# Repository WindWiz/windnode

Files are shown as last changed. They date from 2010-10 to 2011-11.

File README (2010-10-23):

WindWiz
=====================
WindWiz is an open-source weatherstation project. Its primary purpose is to act
as a wind sensor node along the coasts of southern Sweden. The measurements are 
sent back using IP over the cellular network (GPRS).

Features:
---------
* Measurements of wind speed and direction.
* Measurements of air temperature.
* Remote control/configuration via SMS.
* Periodical transmission of current wind conditions over GPRS to a 
configurable IP.
* Rugged design, must withstand rain, snow, temperatures from -20C to +40C.
* Solar powered, with battery backup.
* Reliable, 24/7 operation.
* Total buildcost, ~6000 SEK (swedish currency)

The primary focus of this project is the construction of the actual sensor node
hardware. It includes schematics of the electronics, software (with sourcecode)
running inside the embedded microcontroller, and mechanical details on the 
rugged casing. 

The data samples are transmitted over IP to another system responsible for data
collection and visualization. This is outside the scope of this project.

More information is available at the project homepage:

  http://vind.minimum.se/ (swedish only)

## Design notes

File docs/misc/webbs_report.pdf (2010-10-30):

# WeBBS

# The Weather Bulletin Board System

# Technical Manual

Fahid Jahrami, Arian Lalezari, Justin Lasiewicz,

# Joshua Miers, Nathan Seidle

# Revision: 27 April 2004

# Table of Contents

# H.3 Firstrun.exe | 95 H.4 Secondrun.exe | 96

# Table of Figures

# Table of Equations

# Table of Tables

# 1 Overview

# 1.1 Abstract

# The WeBBS team at the University of Colorado at Boulder designed the Weather Bulletin Board System for autonomous remote weather sensing. The

WeBBS weather station is completely powered by a solar cell charging circuit,

# and communicates wirelessly using cellular telephone technology. The station is programmed to periodically record and store weather conditions from four external sensors: a temperature, pressure, and humidity sensor, as well as an ultrasonic anemometer designed by the WeBBS team to record wind speed

and direction.

The weather conditions can be retrieved in three different ways. Users who are on‐site may use the on‐board LCD display, while off‐site users will have two methods to retrieve data. Users with cellular telephones with SMS service will able to send an SMS text message or a voice call to the station, which will record their telephone number and return an SMS message with weather conditions. Users who cannot access an SMS service will be able to browse weather conditions on a website that will be regularly updated by the weather

station.

# 1.2 Motivation

# While still a young program at only twelve years old, Colorado Crew has quickly grown from one of the most “underprivileged” rowing programs in the nation to one that regularly challenges established varsity teams in

national regattas.

Other than the financial and physical challenges shared by all crew team, the Colorado programs faces an obstacle not common to most established teams: the unpredictable and volatile weather conditions in Boulder. With early morning practices, there is often no way to judge the weather conditions at the Boulder Reservoir without requiring the entire team to arrive at the regular practice time. If practice is cancelled, the entire team is inconvenienced by

having had come to the Reservoir, only to return home.

# With this in mind, it has become the goal of the WeBBS team to provide an

autonomous and financially practical solution for the Colorado Crew team.

# However, we feel that the applications of our product extend well beyond the scope of the Colorado Crew team. For example, ski resorts in Colorado and

elsewhere share the same need for favorable weather to ensure good skiing conditions to their customers. With a weather station at each ski lift, a major resort would easily be able to monitor the conditions throughout their terrain at any time. The same goes for other large‐scale outdoor facilities such as

airports, amusement parks, golf courses, etc.

# 1.3 Block Diagram

# 1.3.1 Power Platform

# 1.3.2 Main Board

# Communications

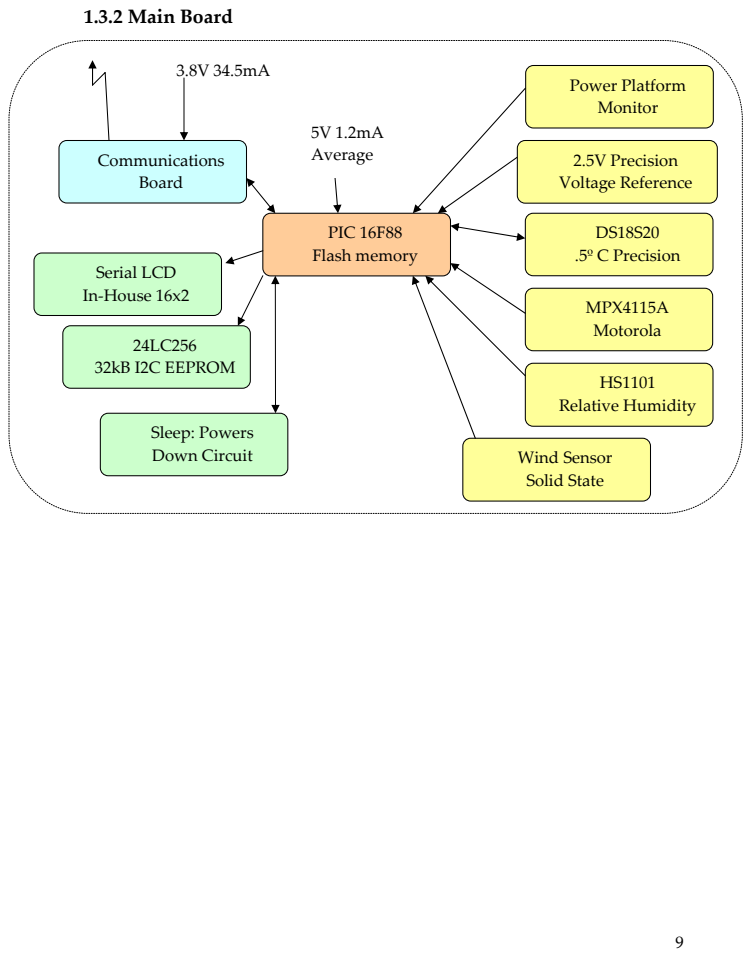
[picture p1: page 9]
DS18S20 .5º C Precision; PIC 16F88 Flash memory; MPX4115A Motorola; HS1101 Relative Humidity; 24LC256 32kB I2C EEPROM; Board; Serial LCD In‐House 16x2; 2.5V Precision Voltage Reference; Wind Sensor Solid State; Power Platform Monitor; Sleep: Powers Down Circuit; 5V 1.2mA Average

# 2 Enclosure

The enclosure of the WeBBS weather station consists of two main components,

# the main enclosure containing the primary electrical systems and the

anemometer enclosure, containing the wind sensor.

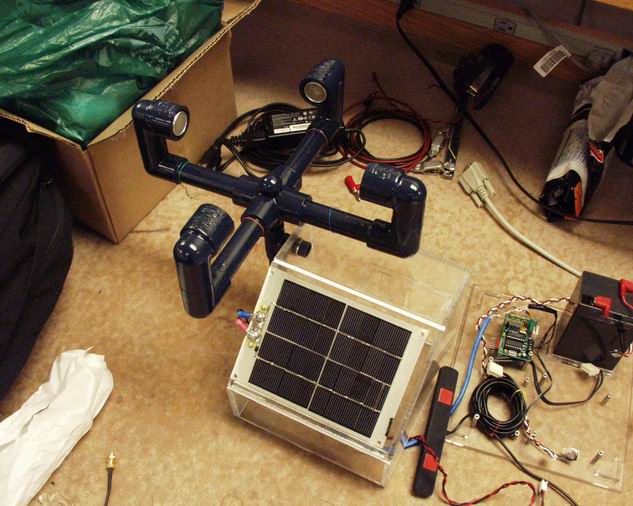
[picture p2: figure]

# Figure 1: Main Housing

# 2.1 Main Enclosure

# 2.1.1 Design Requirement

# The primary design goals of the main enclosure are:

# 1. To minimize the size of the enclosure without compromising the

accessibility of individual internal components.

# 2. To minimize the vulnerability of the internal components to the potentially

harmful external weather conditions.

# 2.1.1.1 Size

# The three components presenting the primary restrictions on the size and shape of the main enclosure are the ultrasonic anemometer, the battery, and the solar panel. Because of its location on the side of the main enclosure, the

ultrasonic anemometer posed a potential threat of toppling the main enclosure.

Furthermore, to adequately fasten the anemometer, we provided that the two fastening locations be at least 3.5 inches apart to maintain stability. For further support, we positioned the battery on the opposite side of the enclosure as a counter‐balance. The battery posed similar height requirements for the enclosure to those of the anemometer. The slanted face of the weather station is designed to provide maximal exposure to the sun for the solar panel. Since

Boulder is at 40° north latitude, the slanted face is elevated by 40°.

# Furthermore, the width of the enclosure is determined by the longest edge of the solar panel. Again, the width requirements posed by the inclusion of the printed circuit boards inside the enclosure were similar to those of the solar

panel.

# 2.1.1.2 Weatherproofing

The two components presenting the primary restrictions on the weatherproofing of the main enclosure are the ultrasonic anemometer and the solar panel. To affix the anemometer to the main enclosure, our design requires two holes in one side of the enclosure. Because holes present a weatherproofing challenge, the lower hole is used doubly to affix the anemometer and provide a snorkel to ventilate the interior of the enclosure

and provide access to external weather conditions for the temperature,

pressure, and humidity sensors. The solar panel presents two challenges to weatherproofing. First, like the anemometer, the leads of the solar panel must be connected to the internal electrical components of the weather station. In order to avoid compromising the structural integrity of the anemometer enclosure, we opt to provide a small hole uniquely for the purpose of the

connectivity of the solar panel. Second, because the solar panel must be tilted, we must weatherproof two non‐perpendicular seams.

# 2.1.2 Materials

The main enclosure is constructed entirely from 0.25‐inch thick clear Plexiglas.

# The perpendicular planes of the enclosure are fastened and weatherproofed with Plastruct plastic solvent cement. The holes and non‐perpendicular solar

panel plane are weatherproofed with weather‐resistant caulk.

# 2.1.3 Construction and Weatherproofing

# All planes of the main enclosure were cut using the Radius laser cutter in the Integrated Teaching and Learning Laboratory (ITLL) machine shop at the

University of Colorado at Boulder.

# All planes were fastened and weatherproofed with Plastruct solvent cement

and caulk.

# 2.1.4 Testing

# The main enclosure was tested under extreme high and low temperature and humidity conditions as well as direct sunlight exposure to ensure the

sustainability of its resistance to weather and internal moisture.

# The enclosure was also tested against stress by applying controlled forces to

each of its exposed surfaces.

# 2.1.5 Drawings

# 2.1.5.1 Conceptual Drawing

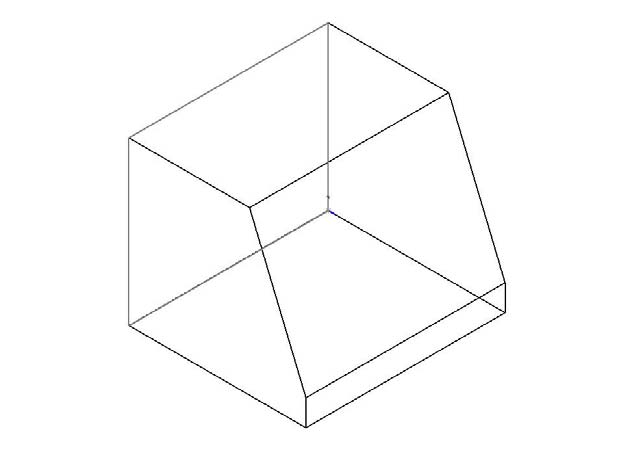
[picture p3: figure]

# Figure 2: 3‐D Conceptual Drawing

# 2.1.5.2 Parts Drawings

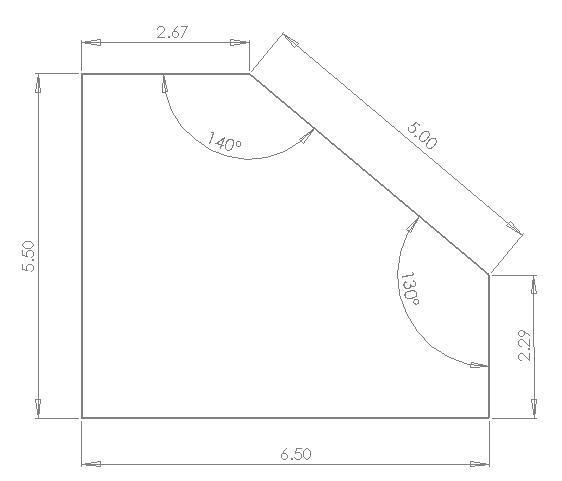
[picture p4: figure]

# Figure 3: Main Enclosure (Left)

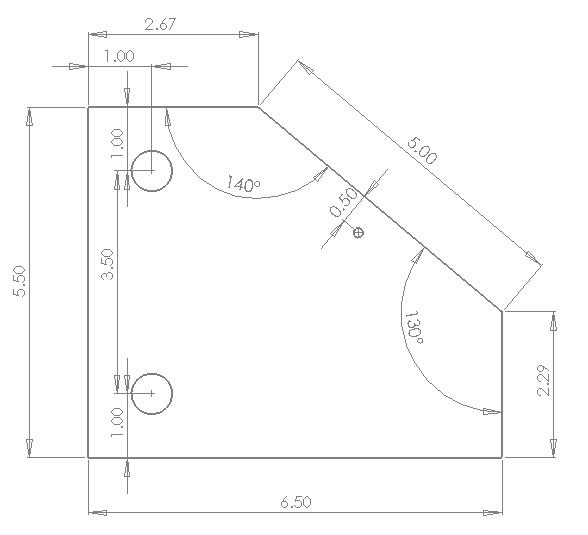
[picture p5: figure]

# Figure 4: Main Enclosure (Right)

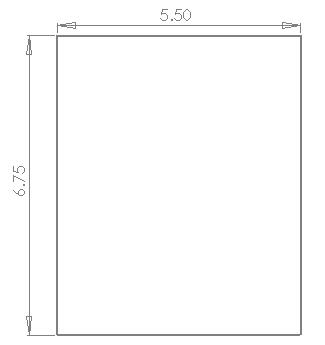
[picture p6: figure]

# Figure 5: Main Enclosure (Back)

# Figure 6: Main Enclosure (Top)

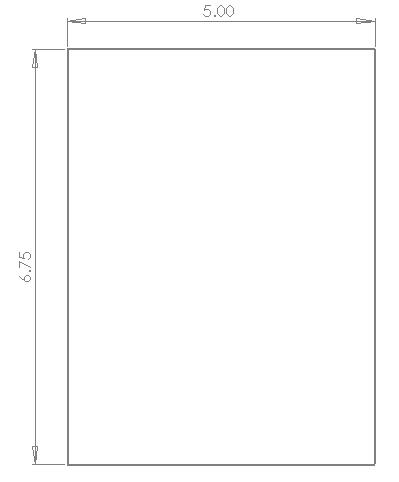
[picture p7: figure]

# Figure 7: Main Enclosure (Solar)

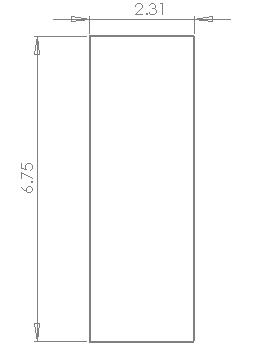
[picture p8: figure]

# Figure 8: Main Enclosure (Front)

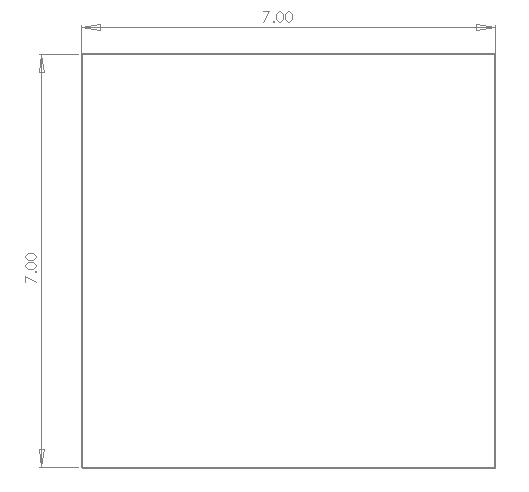
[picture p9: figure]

# Figure 9: Main Enclosure (Base)

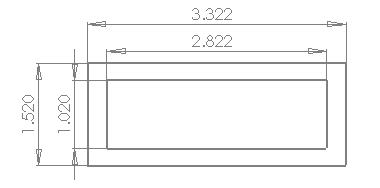
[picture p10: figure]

# Figure 10: Main Enclosure (LCD Frame)

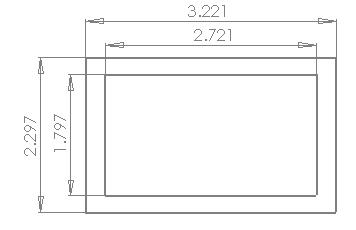
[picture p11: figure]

# Figure 11: Main Enclosure Battery Frame

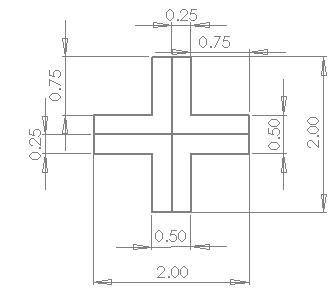
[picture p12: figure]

# Figure 12: Main Enclosure Braces

# 2.2 Anemometer Enclosure

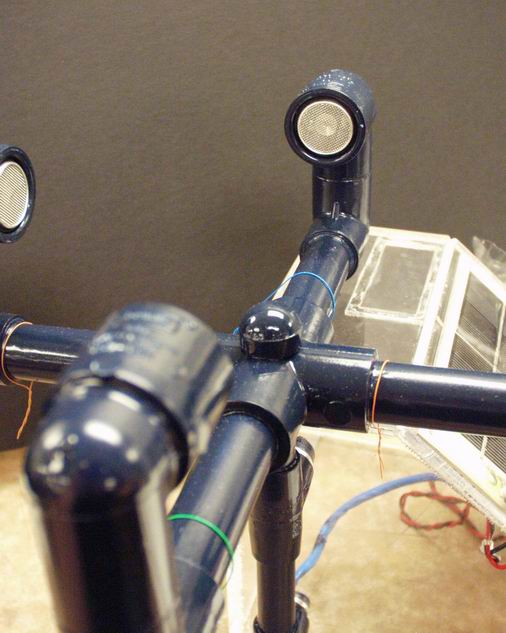
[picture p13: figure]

# Figure 13: Anemometer Enclosure

# 2.2.1 Design Requirements

# The primary design goals of the anemometer enclosure are: 1. To provide stability for the anemometer assembly and align the pairs of

ultrasonic sensors.
2. To weatherproof the critical components of the anemometer.

# 2.2.1.1 Stability

Because of the required size of the anemometer, it is critical that it remains stable and that the ultrasonic sensors remain aligned. For stability, we provide two locations to anchor the anemometer enclosure to the side of the main enclosure. To maintain alignment, we provide that the wind sensor remains smaller than 12 inches in any horizontal direction, and that all connections are

permanently fastened with PVC glue.

# 2.2.1.2 Weatherproofing

The primary concern for weatherproofing the anemometer enclosure is the protection of the internal wires tying the anemometer to the internal components of the weather station. To do this, all connections are sealed and weatherproofed with standard PVC glue. The ultrasonic sensors are weather resistant and are sealed with two o‐rings to protect the inner wires of the

enclosure.

# 2.2.2 Materials

The top assembly of the enclosure requires the use of 0.75‐inch PVC pipe, in order to house the ultrasonic sensors. The vertical assembly of the enclosure is constructed with 0.5‐inch PVC pipe to facilitate the connections to the main enclosure and the top assembly. The ultrasonic sensors are fastened with o‐

rings and all seams are sealed with standard PVC glue.

Each transducer is secured at a distance of 7.3” from its pair.

# 2.2.3 Testing

The enclosure was tested for weather resistance.

# 3 Electrical Systems

There are six main electrical systems in the WeBBS weather station: the main system containing the main microcontroller and several peripheral sensors, the cell module system containing the communications platform, the wind module system containing the microcontroller for the anemometer, the LCD system providing easy‐to‐read on‐site data, the power platform consisting of the solar

panel, battery, and several voltage regulators, and the website receiver station, which logs recorded weather data to a Internet‐available text file.

# 3.1 Main Board

# The main board is responsible for the central processing and monitoring of the weather station. In addition to the primary controller and memory device, the

main board contains three of the four weather sensors.

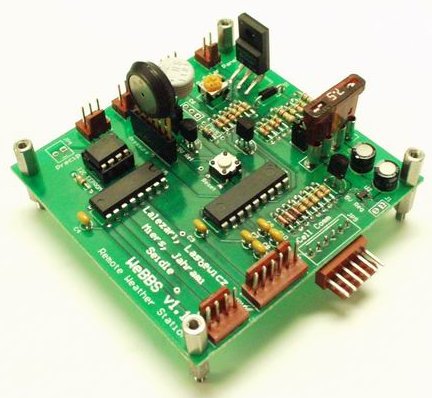
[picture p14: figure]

# Figure 14: Main Board

# 3.1.1 Microcontroller

All electrical systems are coordinated by a Microchip 16F88 microcontroller.

# The 16F88 features the ability to switch clock speeds in real time. To conserve power, the processor is kept at 31.25kHz except while in data recording or communications mode. In order to quicken data processing and

communication, the microcontroller switches to high‐speed mode at 8MHz.

# The 16F88 has 4kb of on‐board Flash program memory. This simplifies the system architecture by minimizing the number of external components

required.

# The 16F88 features the ability to interface to analog devices via seven software‐

configurable analog‐to‐digital channels.

# Because the 16F88 has the ability to change its program memory space on the fly, a proprietary boot loader was developed prior to the project to aide in

programming and debugging.

# All communication protocols (I²C, Dallas 1‐Wire, TTL Serial, RS232) are mimicked with software routines. For debugging purposes, the onboard

UART was utilized.

See Appendix A for microcontroller code.

See Data Sheet Packet for extra information on the boot loader and 16F88.

# 3.1.2 Memory

# The main memory device on the board is the Microchip 24LC256. The primary

use of the EEPROM is to log recorded weather conditions.

# The 24LC256 has 256kb of available flash memory, which gives us enough memory space to record up to 2,000 complete weather station status arrays – or

almost one week of weather conditions at 8 bytes per recording.

The 24LC256 interfaces on the I²C bus protocol.

See Data Sheet Packet for extra information on the 24LC256.

# 3.1.3 Temperature Sensor

The temperature sensor is an off‐the‐shelf sensor from Dallas Semiconductor.

# The DS18S20 measures temperatures from –55°C to +125°C (about ‐67°F to +257°F) with ±0.5°C accuracy. For our purposes, we have limited the

sensitivity of the device to ±1°C (about ±2°F).

The DS18S20 interfaces on the Dallas 1‐Wire protocol.

See Data Sheet Packet for extra information on the DS18S20.

# 3.1.4 Pressure Sensor

# The barometric pressure sensor is an off‐the‐shelf sensor from Motorola. The MPX4115A measures pressure with ±1.5% accuracy between 0°C and 85°C (about 32°F to 185°F). For our purposes, to include a broader range of

temperatures, we have limited the sensitivity of the device to ±5%.

# The MPX4115A interfaces through the TI 4051 8‐channel analog multiplexer to

the on‐board analog‐to‐digital converter of the 16F88.

See Data Sheet Packet for extra information on the MPX4115A.

# 3.1.5 Humidity Sensor

# The relative humidity sensor is an off‐the‐shelf sensor from Humirel. The HS1101 measures relative humidity with ±2% accuracy between –40°C and100°C (about –40°F to 212°F). For our purposes, we have limited the

sensitivity of the device to ±5%.

# The Humidity is determined through observation of the discharge RC time constant of a variable capacitor conjoined with a 983kΩ resistor. The capacitor

# is connected to the microcontroller on a pin that can be changed on the fly

between being an input and output pin. When the pin is set as an output pin,

the capacitor is charged to 5V. It is then discharged through the resistor, after the pin is changed to an input pin. The input pin is a transistor‐to‐transistor‐ logic level input. The TTL threshold for the 16F88 is 2V. Therefore, we can determine the internal capacitance of the sensor by using the equation:

# Equation 1: Humidity Variable Capacitance

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
# From the measured capacitance, we can determine the relative humidity using

a look‐up table derived from the HS1101 data sheet.

See Data Sheet Packet for extra information on the HS1101.

# 3.1.6 Power Requirements

# To conserve power, the main board will actively control the power to each device. Unless the weather station is in recording or communicating mode, all devices will remain powered down, and the microcontroller itself will be in low‐frequency sleep mode. Weather will be recorded and logged every five

minutes, and communications will occur every 15 minutes.

# With only peripheral sensors active, the main board requires 14.3mA to operate. When the microcontroller is set in low‐frequency sleep mode, the current consumption of the main board falls to 12.1mA with peripheral sensors active, and only 960µA with all peripheral sensors powered down. Because

# the main board will only take one five‐second reading every five minutes, we

will draw an average of 1.2mA of current from the main board.

# In order to monitor the current consumption of the board, a pair of leads is available to connect an Ammeter in series with the main power supply of the

board. For field operation, this pair of leads will be connected with a jumper.

# 3.1.7 Schematics

See Appendix B for schematics and PCB layout for the main board.

# 3.2 Communications Board

# The communications board is responsible for operating the wireless relay

between the weather station and a remote user.

# The communications board houses the Telit GM862‐PCS cellular telephone

module, powered by the Analog Devices LT1528 voltage regulator.

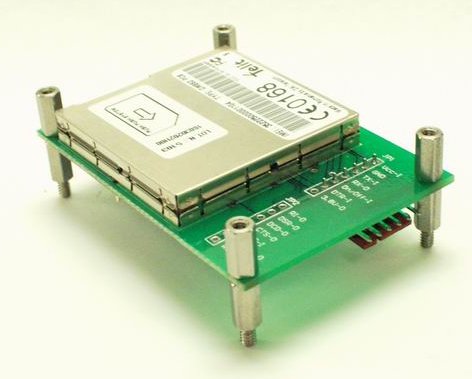
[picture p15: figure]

# Figure 15: Communications Board

# 3.2.1 GSM module

# The GM862‐PCS module has the full suite GPRS abilities: Short Messaging Service (SMS), HyperText Markup Language (HTML), Electronic Mail (E‐

Mail), as well as standard modem and voice capabilities.

# Users must provide a Subscriber Information Module (SIM) card that is

activated under a standard GSM cellular telephone account.

# Support for the GM862‐PCS module can be found by creating an account at the

support forum at http://www.modem‐gsm.de/forum.

See Data Sheet Packet for extra information on the GM862‐PCS.

# 3.2.2 Tri Band Antenna

# The North American PCS network operates on the 1.9GHz band. To connect the GM862‐PCS module to this network, we use the Laipac P1‐GSM tri‐band

omni‐directional half‐wave dipole GSM antenna.

# Though no data sheet is available for this device, any standard tri‐band GSM

antenna will do.

# 3.2.3 Power Requirements

When powered down, the communications board draws 1.4mA quiescent current. When the GSM module is powered up in sleep mode, the board draws 4.9mA. With full power, the board draws an average of 25mA quiescent, and an average of 250mA when communicating or polling for network registration. Assuming two minutes of call‐time (at 250mA) every fifteen minutes, the average current consumption of the communications

module is about 34.5mA.

Unless the module is in active communication, it will remain powered down.

# During periodic communications intervals (every 15 minutes) SMS messages

will be replied to, and data will be sent to the website receiver station.

# 3.2.4 Schematics

See Appendix C for schematics and PCB layout for the communications board.

# 3.3 Wind Module

# The design of the ultrasonic anemometer is based on an existing product available at http://electronickits.com. For our purpose, we have modified the schematic to operate at 25.2kHz, and in two directions, giving us the ability to

calculate the magnitude and direction of the wind.

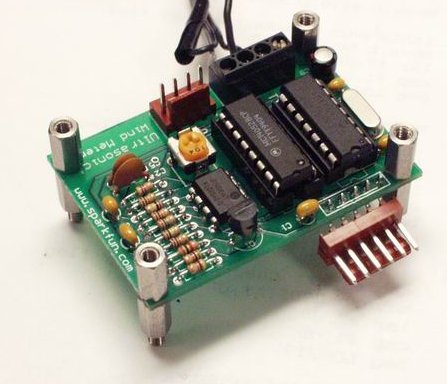
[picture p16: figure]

# Figure 16: Wind Module

# 3.3.1 Ultrasonic Transducers

# The 25.2kHz ultrasonic transducers were selected because of their availability as surplus parts. The 40kHz transducers are also available at

http://www.digikey.com.

# 3.3.2 Microcontroller

# The wind module utilizes the Microchip 16F688 to control each ultrasonic

transceiver and calculate wind speed and direction based on recorded data, prior to communicating to the main processor.

# The 16F688 uses the CC5X compiler’s built‐in 24‐bit non‐standard IEEE

floating point operations for all floating point calculations.

See Data Sheet Packet for extra information on the 16F688.

# 3.3.3 Calculations

# The ultrasonic anemometer uses the 16F688 to process recorded data from two

pairs of ultrasonic transducers. The pairs are oriented at 90° from one another, at 7.3” apart: a north‐south pair, and an east‐west pair.

# The first step in calculating wind speed and magnitude is to determine the speed of sound in each of the four cardinal directions. To do this, the

microcontroller alternately excites each transducer for 80µs, or about 2 periods,

# and counts the number of processor clock cycles (at 200ns per cycle) between

transmission of a signal from one transducer to its reception at its pair.

# For example, if it takes N clock cycles from the transmission time of the south transducer to the reception time at the north transducer, the speed of sound in the northerly direction, in inches per cycle is:

# Equation 2: Speed of Sound in North Direction

N

# x VN

∆ =

# Where the quantity ∆x is the distance between the north and south

transducers: 7.3”.

# Similarly, the speed of sound in the south direction, in inches per cycle can be expressed as:

# Equation 3: Speed of Sound in South Direction

S

# x VS

∆ =

To determine the wind speed in the northerly direction, we simply subtract the second quantity from the first and divide by two (since both sensors detect a change in the speed of sound when wind is blowing, we must divide by two so that we do not double‐count for wind). Our equation for the northerly wind, still in inches per cycle becomes:

# Equation 4: Northerly Wind Speed

NS

# x S N

NS

# S S x N x

x
N

x
V | V W | N | S

N

∆ − = ∆ − ∆ =

∆ − ∆
= − = | 2 | 2 | 2 | 2

# To convert this speed to the more familiar units of miles per hour, some dimensional analysis is required to obtain a conversion constant:

# Equation 5: Wind Speed Conversion Constant

K

# in hr

# cycle mi

in

mi
hr

ns
ns
cycle | = ⋅
⋅ ≅ ⋅ | 284091
63360

3.6 10 1
200
1 | 12

# Such that the northerly wind speed in miles per hour becomes:

# Equation 6: Updated Northerly Wind Speed

NS

x S N WN | K ∆ | − = | 2

# Because the value of Dx/2 can also be known a priori, an even more robust conversion constant can be derived:

# Equation 7: Updated Wind Speed Conversion Constant

hr

x | cycle mi L K | ⋅ = | ≅
∆ = | 1036932
2

7.3 284091
2

# And the final value of the wind speed in the northerly direction in miles per hour becomes:

# Equation 8: Final Northerly Wind Speed

NS

# S N WN L − =

# Similar calculations are made for the easterly wind speed, which allows us to determine the overall wind magnitude by applying the Pythagorean theorem:

# Equation 9: Wind Magnitude

()() ² | 2 W | = WN | + WE

# To avoid the implementation of inverse trigonometric functions on the

microcontroller, a look‐up table is used to determine the trajectory of the wind.

# First, a preliminary angle between 0° and 85° is determined by comparing the relative magnitudes of WN and WE. Special cases are made for a complete lack of wind in either the northerly or easterly direction, and then the ratio of

# northerly wind magnitude to easterly wind magnitude is computed, and used as input to the following look‐up table:

# Table 1: Wind Bearing Look‐up Table

W N W E min | W N W E max | Angle
‐0.043660943 | 0.043660943 | 0
0.043660943 | 0.131652498 | 5
0.131652498 | 0.221694663 | 10
0.221694663 | 0.315298789 | 15
0.315298789 | 0.414213562 | 20
0.414213562 | 0.520567051 | 25
0.520567051 | 0.637070261 | 30
0.637070261 | 0.767326988 | 35
0.767326988 | 0.916331174 | 40
0.916331174 | 1.091308501 | 45
1.091308501 | 1.303225373 | 50
1.303225373 | 1.569685577 | 55
1.569685577 | 1.920982127 | 60
1.920982127 | 2.414213562 | 65
2.414213562 | 3.171594802 | 70
3.171594802 | 4.510708504 | 75
4.510708504 | 7.595754113 | 80
7.595754113 | 22.90376555 | 85

With these calculations, the 16F688 can report wind speed and direction.

# 3.3.4 Power Requirements

# Like the temperature, pressure, and humidity sensors, the ultrasonic anemometer is considered a peripheral sensor, and may only be powered up

when weather conditions are recorded.

# While recorded and processing wind speed data, the wind module requires

7mA – about half of the power consumption from the main board.

# 3.3.5 Schematics

See Appendix D for schematics and PCB layout for anemometer board.

See Appendix E for wind sensor code.

# 3.4 Serial LCD Module

# For demonstration purposes and for some field models, an LCD will be made available on the weather‐station for on‐site retrieval of weather data. The LCD

used in our application is the Xiamen Ocular K21602.

# See Data Sheet Packet for extra information on the K21602 LCD and the

Sparkfun LCD backpack.

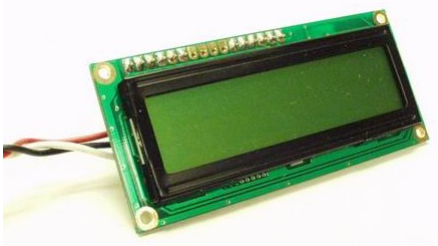
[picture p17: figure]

# Figure 17: Serial LCD Module

# 3.4.1 Power Requirements

The LCD module draws 3mA without backlight, and 60mA with backlight.

# The backlight will be software activated, and will be illuminated for 10 seconds after each weather recording is logged. Because the LCD will only be illuminated for 10 seconds in each five‐minute interval, our average current

consumption will be 4.9mA.

# 3.4.2 Schematics

See Appendix F for code, schematics, and PCB layout.

# 3.5 Power Platform

On average, the WeBBS weather station will draw 1.2mA from the main board,

# 34.5mA from the communications board, and 4.9mA from the LCD board, for

a total average consumption of 40.6mA.

# To satisfy this power requirement, the weather station uses a solar panel to constant‐voltage charge a high‐capacity sealed lead‐acid (SLA) battery. The

SLA battery is used to power the weather station during poor solar visibility.

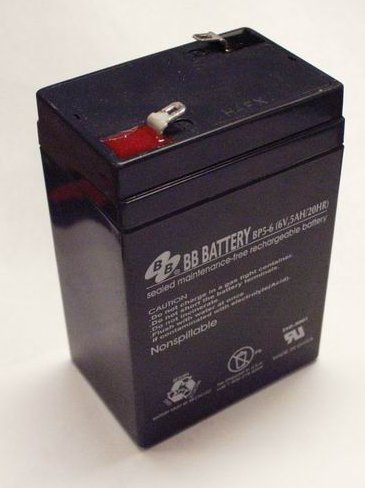
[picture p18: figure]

# Figure 18: Battery

# 3.5.1 Design Requirements

# To be fully autonomous, the WeBBS weather team designed for the weather

station to be able to survive three days without solar charging.

# Furthermore, power requirements necessitate that the weather station gain power even during the poorest solar conditions in the winter months in

Colorado.

# Because of variable nature of solar power, it is important that the battery charging circuit is able to regulate the voltage applied to the battery during

charging.

# Because of the restrictions on power from the necessary components of the WeBBS weather station, it is important that low‐overhead, low current draw voltage regulators are used to minimize unnecessary quiescent current

consumption.

# 3.5.2 Solar Panel

# A solar panel will be used exclusively to recharge the power of the weather station in the field. The WeBBS weather station uses a high efficiency Solar World SPE‐225‐6, a 9V, 225mA solar panel rated for up to 2W of power

delivery.

See Data Sheet Packet for extra information SPE‐225‐6.

# 3.5.3 Battery

# The WeBBS weather station is powered with a BB BP5‐6‐T1 battery. The battery rated for a 5A‐hr capacity. At 40.6mA average draw, this battery provides enough power to operate the weather station for 123 hours – over

five days with no sun.

See Data Sheet Packet for extra information on the BB BP5‐6‐TI.

# 3.5.4 Calculations

# With the main board and all peripheral weather sensors fully powered only during readings, and with the communications module powered only during two minutes of call time every 15 minutes, the WeBBS weather station draws

an average of 40.6mA – or about 975mA‐hr per day.

According the National Renewable Energy Labs (NREL), a typical winter day will have no more than four hours of good solar conditions. Because our solar cell generates 250mA under such conditions, we expect to recharge at least 1A‐ hr of battery capacity even on days with the poorest of solar conditions. As this is greater than the battery capacity required to operate the weather station each day, we expect to be able to maintain a fully charged battery throughout

the winter.

# 3.5.5 Charging Circuit

When the sealed lead‐acid (SLA) battery is near full capacity, the charging circuit on the WeBBS weather station is designed to charge the battery according to a constant‐voltage charging scheme. This scheme mimics a trickle charge scheme, but the charging current falls to zero as the battery approaches full capacity. This charging scheme prevents overcharging, and improves the

longevity of the battery.

When the battery’s capacity falls below 80%, the charging circuit enters a constant‐current charging scheme that maximizes the efficiency of the solar cell in its ability to charge the battery. This scheme mimics a flash‐charge scheme, and allows the weather station to rapidly regain battery capacity

when it falls below ideal levels.

See Appendix G for power platform schematics.

# 3.5.6 Voltage Regulators

# Several voltage regulators are required to provide adequate voltages at rated currents to various components of the weather station. Again, it is critical that these components contribute as little as possible to the current consumption of

the overall system.

3.5.6.1 Communications Board The communications board uses a Linear Technology LT1528 Voltage Regulator. The Telit GM862 module has the interesting requirement of needing up to 2A during peak transmission at 3.8V. Due to the possible high current draw and need for minimum quiescent current to minimize current

consumption, a suitable regulator was needed.

# The LT1528 solves both these problems with features like 400µA of quiescent

current and the ability to source up to 3A with adequate heat sinking.

# The LT1528 is set to output 3.3V. This output voltage can be altered using two reference resistors. For our purpose, the Telit datasheet recommends 370Ω and 47Ω. Using these resistors we draw 3.8V / 417Ω = 9.11mA – nearly 32% of

# our actual overall current consumption. By increasing these resistors by a factor of ten (3.7kΩ and 470Ω), the wasted current consumption is reduced to

less than 1mA.

# 3.5.6.2 Main Board

# The main board utilizes a 5V LDO low‐noise voltage regulator. The TI TPS77050DBVR 5V regulator has 13µA of quiescent current with very low

# ripple (less than 50mV). It does all this by sacrificing output current. The TPS regulator can only source up to 50mA. Luckily, our main board never

approaches this level of consumption (14.3mA max avg.).

# 3.5.6.3 Charging Circuit

The SLA battery is charged using the Sharp PQ20RX11 variable voltage regulator. This regulator has a low voltage dropout (LDO) of 500mV maximum and was determined experimentally to be just over 300mV. This means that our solar cell output voltage can dip down to 6.9V (very cloudy) and continue to push small amounts of current into the battery. The charging regulator is set to output 6.3 volts (measured after the diode) to put the battery

into constant voltage charging. This diode, on the circuit side of the regulator,

# is installed to prevent the battery from pushing current backwards through the charging regulator during the night. Backward biasing the charging regulator

would stress the part and possibly shorten its lifespan.

# 3.6 Website Receiver Station

To provide weather information to customers without access to SMS devices,

# the WeBBS weather station is able to maintain and regularly update a website

with current weather conditions.

# 3.6.1 Overview

# Simultaneously connected to a phone line via a traditional modem and to the internet via an Ethernet connection, the website receiver station is able to

automatically receive and log incoming data calls from the weather station, and store the data as a Web‐available text file.

# 3.6.2 Code

See Appendix H for ProComm and C++ routines.

# 4 Parts List

# 4.1 Main Board

# Table 2: Main Board Bill of Materials

Weather Station Bulletin Board System | 25 Units | 100 Units
Manufacturer Part # | Digikey Part # | Description | Designator Package | Qty | Price | Sum | Price | Sum
Logic
PIC16F88-I/SS | PIC16F88-I/SS-ND 16F88 PIC microcontroller | U3 | DIP-18 | 1 | $2.66 | $2.66 | $2.47 | $2.47
| | .1uF Microcontroller Support Capacitor | C3 | TH | 1 | $0.10 | $0.10 | $0.06 | $0.06
| | Momentary Reset SPST | S1 | TH | 1 | $0.10 | $0.10 | $0.10 | $0.10
| | 10K Pull-Up Resistor +/-5% | R12 | TH | 1 | $0.00 | $0.00 | $0.00 | $0.00
22-23-2061 | WM4204-ND | ICSP Header | JC1 | HXDR1X5 | 0 | $0.53 | $0.00 | $0.00 | $0.00
24LC256-I/SM | 24LC256-I/SM-ND | 256kBit I2C EEPROM | U4 | DIP-8 | 1 | $1.74 | $1.74 | $1.47 | $1.47
| | 4.7K SDA Pull-Up Resistor +/-5% | R13 | TH | 1 | $0.04 | $0.04 | $0.04 | $0.04
| | 4-Pin Molex Connector - Debugging Comm | JP10 | CM4 | 1 | $0.25 | $0.25 | $0.25 | $0.25

Basic Sensors
CD74HCT4051E | 296-2119-5-ND | 8 Channel Analog Multiplexor | U5 | DIP-16 | 1 | $0.45 | $0.45 | $0.45 | $0.45
| | .1uF Support Capacitor | C4 | TH | 1 | $0.10 | $0.10 | $0.06 | $0.06
HS1101 | HS1101-ND | HS1101 Humidity Sensor | C5 | HDR1x3 | 1 | $8.65 | $8.65 | $5.69 | $5.69
| | 820K +/-1% Resistor | R14 | TH | 1 | $0.05 | $0.05 | $0.03 | $0.03
| | Calibration Capacitor | C6 | HDR1x3 | 1 | $8.65 | $8.65 | $5.69 | $5.69
| | 820K +/-1% Resistor | R15 | TH | 1 | $0.05 | $0.05 | $0.03 | $0.03
MPX4115A | MPX4115A-ND | MPX4115A Pressure Sensor | U7 | HDR1x6 | 1 | $13.78 | $13.78 | $12.98 | $12.98
DS18S20 | DS18S20-ND | DS18S20 Temperature Sensor | JP1 | CM3 | 2 | $3.80 | $7.60 | $2.28 | $4.56
| | 4.7K Pull-Up Resistor +/-5% | R16 | TH | 1 | $0.00 | $0.00 | $0.00 | $0.00
LT1009CLP | 296-9585-5-ND | Precision 2.5V Zener | D2 | TO-92 | 1 | $0.63 | $0.63 | $0.50 | $0.50
| | 10K Bias Resistor +/-5% | R17 | TH | 1 | $0.00 | $0.00 | $0.00 | $0.00

Charging Power Supply
SPE-225-6 | --- | 9V 225mA Solar Cell | JP8 | CM2 | 1 | $49.00 | $49.00 | $49.00 | $49.00
BP4-6-T1 | --- | 6V 5AHr Lead Acid Battery | JP7 | CM2 | 1 | $6.45 | $6.45 | $6.45 | $6.45
| | Fuse | F1 | TH | 1 | $0.25 | $0.25 | $0.25 | $0.25
PQ20RX11 | 425-1722-5-ND | 1A Adjustable LDO Regulator | U1 | Special | 1 | $1.32 | $1.32 | $0.96 | $0.96
| | 43K Power Control Pull-Up Resistor +/-5% | R18 | TH | 1 | $0.00 | $0.00 | $0.00 | $0.00
| | 1K Adjustment Resistor | R1 | TH | 1 | $0.04 | $0.04 | $0.02 | $0.02
| | 10K Adjustment TrimPot | RT1 | TH | 1 | $0.04 | $0.04 | $0.02 | $0.02
| | Forward Control Diode 4001 | D1 | TH | 1 | $0.04 | $0.04 | $0.04 | $0.04
| | Peripheral Power Control GP NPN BJT | Q1 | TO-92T | 1 | $0.05 | $0.05 | $0.05 | $0.05
TPS77050DBVR | 296-11052-1-ND | 5V 150mA LDO Low IQ | U2 | SOT-23A | 1 | $0.73 | $0.73 | $0.58 | $0.42
| | 10uF/25V Filtering Capacitor - Raw | C1 | TH | 1 | $0.18 | $0.18 | $0.12 | $0.12
| | 10uF/25V Filtering Capacitor - 5V | C2 | TH | 1 | $0.18 | $0.18 | $0.12 | $0.12
| | 1Ohm Moitor Resistor - Stage 1-2 | R2 | TH | 1 | $0.04 | $0.04 | $0.02 | $0.02
| | 100K Monitor Resistor - Stage 1 | R3 | TH | 1 | $0.04 | $0.04 | $0.02 | $0.02
| | 43K Monitor Resistor - Stage 1 | R4 | TH | 1 | $0.04 | $0.04 | $0.02 | $0.02
| | 100K Monitor Resistor - Stage 2 | R5 | TH | 1 | $0.04 | $0.04 | $0.02 | $0.02
| | 43K Monitor Resistor - Stage 2 | R6 | TH | 1 | $0.04 | $0.04 | $0.02 | $0.02
| | 1Ohm Moitor Resistor - Stage 2-3 | R11 | TH | 1 | $0.04 | $0.04 | $0.02 | $0.02
| | 100K Monitor Resistor - Stage 3 | R7 | TH | 1 | $0.04 | $0.04 | $0.02 | $0.02
| | 43K Monitor Resistor - Stage 3 | R8 | TH | 1 | $0.04 | $0.04 | $0.02 | $0.02
| | 100K Monitor Resistor - Stage 4 | R9 | TH | 1 | $0.04 | $0.04 | $0.02 | $0.02
| | 43K Monitor Resistor - Stage 4 | R10 | TH | 1 | $0.04 | $0.04 | $0.02 | $0.02

Cellular Data Module
Cellular Data Module | --- | --- | 1 | $120.00 $120.00 $120.00 $120.00
| | 5-Pin Molex Connector - Cellular Connection | JP9 | Special | 1 | $0.25 | $0.25 | $0.25 | $0.25
| | TX Diode Drop | D3, 4, 5 | TH | 3
| | TX Caps .1uF Universal | C7, 8 | TH | 2
| | DTR Diode Drop | D6, 7, 8 | TH | 3
| | DTR Caps .1uF Universal | C9, 10 | TH | 2
| | On/Off Transistor | Q2 | TO-92T | 1
| | 47K On/Off Resistors | R19, 20 | TH | 2
| | 10K Pull Down Resistors for DTR/TX | R21, 22 | TH | 2

Ultrasonic Wind Sensor

--- | --- | Ultrasonic Wind Meter Module | JP2 | CM4 | 1 | $10.00 | $10.00 | $10.00 | $10.00

Serial LCD
--- | --- | 2x16 Serial LCD Module | JP3 | CM3 | 1 | $10.00 | $10.00 | $10.00 | $10.00

Precipitation Sensor
--- | --- | 2 Wire Precipitation Sensor | JP4 | CM2 | 1 | $0.00 | $0.00 | $0.00 | $0.00

PCB
Olimex | 2-3 Weeks | $26 Per Panel - 6.3"x3.3" - 12 Boards | -- | -- | 1 | $2.80 | $2.80 | $2.80 | $2.80

Enclosure
| | $40 per 3 + $15 for Assembly | | | 1 | $18.33 | $18.33 | $18.33 | $18.33
Total: | $264.91 Total: | $253.45

# 4.2 Wind Sensor

Table 3: Wind Sensor Bill of Materials Ultrasonic Wind Meter | 25 Units | 100 Units
Manufacturer Part # | Digikey Part # | Description | Designator Package Qty | Price | Sum | Price | Sum
Logic
PIC16F630 | PIC16F630 | 16F630 PIC microcontroller | U1 | DIP-14 | 0 | $1.27 | $0.00 | $1.20 | $0.00
PIC16F688 | PIC16F688 | 16F688 PIC microcontroller | U1 | DIP-14 | 1 | $1.97 | $1.97 | $1.87 | $1.87
C320C104M5U5CA | 399-2155-ND | .1uF Microcontroller Support Cap | C1 | TH | 1 | $0.09 | $0.09 | $0.09 | $0.09
ECE-A1HKS2R2 | P994-ND | 2.2uF Power Decoupling Cap | C9 | RC-TH | 1 | $0.14 | $0.14 | $0.11 | $0.11
ECS-200-20-4 | X439-ND | 20Mhz Xtal - HC-49/US | Y1 | Xtal-1 | 1 | $0.52 | $0.52 | $0.41 | $0.41
C315C270J2G5CA | 399-1891-ND | 27pF Xtal Capacitors | C7,C8 | TH | 2 | $0.21 | $0.42 | $0.15 | $0.30
| | 4-Pin Molex Connector - Sensors | JP2 | TH | 1 | $0.35 | $0.35 | $0.28 | $0.28
ED555/4DS | ED1516-ND | 4 Terminal Screw Connector - Comm | JP1 | TH | 1 | $0.72 | $0.72 | $0.64 | $0.64
ED555/4DS | ED1516-ND | 4 Terminal Screw Connector - Sensors | JP2 | TH | 0 | $0.72 | $0.00 | $0.64 | $0.00

Ultrasonic Wind Sensor
--- | --- | Ultrasonic Sensors - 25kHz | | --- | 4 | $1.00 | $4.00 | $1.00 | $4.00
LM358AP | 296-9554-5-ND LM358 Dual OpAmp | U3 | DIP-8 | 1 | $0.32 | $0.32 | $0.24 | $0.24
2N3904 | 2N3904FS-ND | NPN GP BJT Transistor | Q1 | TO-92T | 1 | $0.12 | $0.12 | $0.09 | $0.09
CD74HC4052E | 296-9217-5-ND 74LF4052 Analog Multiplexor | U2 | DIP-16 | 1 | $0.36 | $0.36 | $0.27 | $0.27
EVN-D8AA03B15 | D4AA15-ND | 100K Potentiometer | R10 | TH | 1 | $0.25 | $0.25 | $0.18 | $0.18
CFR-12JB-4K7 | 4.7KEBK-ND | 4.7K +/-5% Resistor 1/8 Watt | R9 | TH | 1 | $0.06 | $0.06 | $0.02 | $0.02
CFR-12JB-47K | 47KEBK-ND | 47K +/-5% Resistor | R1 | TH | 1 | $0.06 | $0.06 | $0.02 | $0.02
CFR-12JB-1K0 | 1.0KEBK-ND | 1K +/-5% Resistor | R11 | TH | 1 | $0.06 | $0.06 | $0.02 | $0.02
CFR-12JB-10K | 10KEBK-ND | 10K +/-5% Resistor | R4,5,6,7 | TH | 4 | $0.06 | $0.22 | $0.02 | $0.09
CFR-12JB-100K | 100KEBK-ND | 100K +/-5% Resistor | R2, R3 | TH | 2 | $0.06 | $0.11 | $0.02 | $0.05
CFR-12JB-1M0 | 1.0MEBK-ND | 1M +/-5% Resistor | R8 | TH | 1 | $0.06 | $0.06 | $0.02 | $0.02
D100D20C0GH63L6 | 1326PH-ND | 10pF 15V Capacitor | C6 | TH | 1 | $0.07 | $0.07 | $0.06 | $0.06
D101K20Y5PH63L6 | 1371PH-ND | 100pF 15V Capacitor | C2 | CDR | 1 | $0.07 | $0.07 | $0.06 | $0.06
D102K20Y5PH63L6 | 1383PH-ND | 1000pF-1nF 15V Capacitor | C5 | CDR | 1 | $0.08 | $0.08 | $0.06 | $0.06
C320C104M5U5CA | 399-2155-ND | 100nF- Universal .1uF | C3, C4 | TH | 2 | $0.09 | $0.17 | $0.09 | $0.17

PVC Housing
| | 90 Degree 3/4" to 1/2" Bushing | -- | -- | 4 | $0.59 | $2.36 | $0.39 | $1.56
| | 90 Degree 1/2" L | -- | -- | 4 | $0.18 | $0.72 | $0.18 | $0.72
| | 4-Way Cross 1/2" | -- | -- | 1 | $1.95 | $1.95 | $1.00 | $1.00
| | 1/2" Pipe | -- | -- | 1 | $0.30 | $0.30 | $0.30 | $0.30

PCB
| | | -- | -- | 1 | $1.70 | $1.70 | $1.35 | $1.35

Assembly
Manual Paid - 1hr @ 10/hr | -- | -- | 0 | $10.00 | $0.00 $10.00 $0.00
| | Manufactured | -- | -- | 0 | $5.00 | $0.00 | $5.00 | $0.00
| | | | | | Total: | $17.23 | | $13.99
Retail: $34.47 | $27.98

# 4.3 Serial LCD

# Table 4: Serial LCD Bill of Materials

Serial Enabled LCD Backpack | 25 Units | 100 Units
Manufacturer Part # | Digikey Part # | Description | Designator | Package | Qty | Price | Sum | Price | Sum
Logic
PIC16F630 | PIC16F630 | 16F630 PIC microcontroller | U1 | DIP-14 | 1 | $1.46 | $1.46 | $1.20 | $1.20
C320C104M5U5CA | 399-2155-ND | .1uF Microcontroller Support Cap | C1 | TH | 1 | $0.03 | $0.03 | $0.03 | $0.03
ED555/3DS | ED1515-ND | 3 Terminal Screw Connector | JP1 | TH | 1 | $0.54 | $0.54 | $0.48 | $0.48

LCD
CFR-12JB-330R | D4AA14-ND | TrimPot - 10K | R1 | TH | 1 | $0.25 | $0.25 | $0.18 | $0.18
BC337 | BC337OS-ND | 800mA BJT | Q1 | TH | 1 | $0.21 | $0.21 | $0.14 | $0.14
| | 2x16 Character LCD w/BL - Olimex | -- | -- | 1 | $6.00 | $6.00 | $6.00 | $6.00
| | 4x16 Character LCD - Timeline | -- | -- | 0 | $5.70 | $0.00 | $5.70 | $0.00
| | 12 Total Connection Pins @ .021 | JP2, JP3 | TH | 1 | $0.25 | $0.25 | $0.25 | $0.25

PCB
| | 1"x1.75" - $.50/sqin | -- | -- | 1 | $0.88 | $0.88 | $0.88 | $0.88
Total: | $9.62 | $9.16
Retail: | $19.23 | $18.32

# 5 Conclusions

# The WeBBS project turned out to be much more complex than we initially anticipated. The design aspects were challenging and rewarding, and allowed

each of us to learn new skills and apply them to the project.

# Though much of the technology we used was common to at least one group member, the Telit module was something completely new for all of us. Our eventual success with the module was a $240 defining moment for our group

and for our project.

# Another new aspect for most of us was the development and optimization of a low‐power system. This quality of the system manifested itself in almost every

component in the design.

# While our system is not yet completely deployable, we have reached proof‐of‐ concept, and feel that taking the product to market is a viable next step for the

project.

# Overall, we feel that this has been a fun, interesting, and rewarding experience

with a great group.

# 6 Acknowledgements

# Zach “How to Eat Five Batteries” Miers

# Figure 19: How to eat five batteries

# Sarah “We Just Don’t Have the Power” Macumber

# Figure 20: Scotty

# Spark Fun Electronics

# Figure 21: Buy our products

# Mark Eaton in the machine shop in the ITLL

# Appendix A: Main Microcontroller Code

# This appendix contains the code from the main board microcontroller (16F88)

with annotations.

# A.1 Delay.c

# These are the most basic routines to cause the processor to delay at various

oscillator configurations.

/*
7/23/02
Nathan Seidle
nathan.seidle@colorado.edu

Delays for... Well, everything.

11-11 Updated the delays - now they actually delay what they say they should.

10-11-03 Updated delays. New CC5X compiler is muy optimized.

*/

//Really short delay
void delay_us(uns16 x)
{

#ifdef Clock_4MHz

//Calling with 10us returns 69us for ( ; x > 0 ; x--);
#endif

#ifdef Clock_8MHz

//Calling with 1us returns 11us //Calling with 10us returns 56us //for ( ; x > 0 ; x--);

//Calling with 1us returns 7.5us //Calling with 10us returns 48 //Calling with 1000us returns 4.5ms while(--x);

//while(x--);
#endif

#ifdef HS_Osc

//Calling with 10us returns 13 us //Calling with 1us returns 1.8us while(--x) nop();
#endif

}

//General short delay
void delay_ms(uns16 x)
{

#ifdef Clock_4MHz

//Clocks out at 1002us per 1ms int y;
for ( ; x > 0 ; x--)
for ( y = 0 ; y < 108 ; y++); #endif

#ifdef Clock_8MHz

//Clocks out at 1006us per 1ms uns8 y, z;
for ( ; x > 0 ; x--)
for ( y = 0 ; y < 4 ; y++)
for ( z = 0 ; z < 69 ; z++); #endif

#ifdef HS_Osc

uns8 y, z;
//Clocks out to 1.00ms per 1ms //9.99 ms per 10ms
for ( ; x > 0 ; x--)
for ( y = 0 ; y < 4 ; y++)
for ( z = 0 ; z < 176 ; z++); #endif

}

//Delays in 31.25kHz Low Power mode using the internal 31.25kHz oscillator void delay_s_lp(uns16 x)
{

uns16 y;
//Clocks out to 1.001s per 1s for ( ; x > 0 ; x--)
for ( y = 0 ; y < 775 ; y++); }

# A.2 StdIO.c

# These functions are akin to C++ printf functions. They are written to facilitate

I/O on a microcontroller platform, including the hardware UART.

/*
5/21/02
Nathan Seidle
nathan.seidle@colorado.edu

Serial Out Started on 5-21
rs_out Perfected on 5-24

1Wire Serial Comm works with 4MHz Xtal
Connect Serial_Out to Pin2 on DB9 Serial Connector Connect Pin5 on DB9 Connector to Signal Ground 9600 Baud 8-N-1

5-21 My first real C and Pic program.
5-24 Attempting 20MHz implementation
5-25 20MHz works
5-25 Serial In works at 4MHz
5-25 Passing Strings 9:20
5-25 Option Selection 9:45

6-9 'Stdio.c' created. Printf working with %d and %h
7-20 Added a longer delay after rs_out
Trying to get 20MHz on the 16F873 - I think the XTal is bad. 20MHz also needs 5V Vdd. Something I dont have.
2-9-03 Overhauled the 4MHz timing. Serial out works very well now.

6-16-03 Discovered how to pass string in cc5x
void test(const char *str);
test("zbcdefghij"); TXREG = str[1];

Moved to hardware UART. Old STDIO will be in goodworks.

Works great! Even got the special print characters (\n, \r, \0) to work.

*/

//#define Serial_Out RA2
//#define Serial_In RA1

//Clock is defined in Delay.c!!!

//int counter;

//Setup the hardware UART TX module void enable_uart_TX(bit want_ints) {

#ifdef Clock_4MHz

#ifdef Baud_9600

SPBRG = 6; //4MHz for 9600 Baud #endif
#endif

#ifdef Clock_8MHz

#ifdef Baud_4800

SPBRG = 25; //8MHz for 4800 Baud #endif
#ifdef Baud_9600

SPBRG = 12; //8MHz for 9600 Baud #endif
#endif

#ifdef Crazy_Osc

#ifdef Baud_9600

SPBRG = 32; //20MHz for 9600 Baud #endif
#endif

#ifdef HS_Osc

#ifdef Baud_9600

SPBRG = 31; //20MHz for 9600 Baud #endif

#ifdef Baud_4800

SPBRG = 64; //20MHz for 4800 Baud #endif
#endif

BRGH = 0; //Normal speed UART

SYNC = 0;
SPEN = 1;

if(want_ints) //Check if we want to turn on interrupts

{
TXIE = 1;
PEIE = 1;
GIE = 1;
}

TXEN = 1; //Enable transmission }

//Setup the hardware UART RX module void enable_uart_RX(bit want_ints) {

#ifdef HS_Osc

#ifdef Baud_9600

SPBRG = 31; //20MHz for 9600 Baud #endif

#ifdef Baud_4800

SPBRG = 64; //20MHz for 4800 Baud #endif
#endif

BRGH = 0; //Normal speed UART

SYNC = 0;
SPEN = 1;

CREN = 1;

//WREN = 1;

if(want_ints) //Check if we want to turn on interrupts {
RCIE = 1;
PEIE = 1;
GIE = 1;
}

}

//Sends nate to the Transmit Register void putc(uns8 nate)
{
while(TXIF == 0);
TXREG = nate;
}

uns8 getc(void)
{
while(RCIF == 0);
return (RCREG);
}

//Returns ASCII Decimal and Hex values uns8 bin2Hex(char x)
{
skip(x);
#pragma return[16] = "0123456789ABCDEF" }

//Prints a string including variables
void printf(const char *nate, int16 my_byte) {

uns8 i, k, m, temp;
uns8 high_byte = 0, low_byte = 0;
uns8 y, z;

uns8 decimal_output[5];

for(i = 0 ; ; i++)
{
k = nate[i];

if (k == '\0')
break;

else if (k == '%') //Print var {
i++;
k = nate[i];

if (k == '\0')
break;
else if (k == '\\') //Print special characters {
i++;
k = nate[i];

putc(k);

} //End Special Characters
else if (k == 'b') //Print Binary

{
for( m = 0 ; m < 8 ; m++ )
{
if (my_byte.7 == 1) putc('1'); if (my_byte.7 == 0) putc('0'); if (m == 3) putc(' ');

my_byte = my_byte << 1;
}
} //End Binary
else if (k == 'd') //Print Decimal
{
for(m = 4 ; my_byte > 0 && m < 255 ; m--) {
temp = my_byte % (uns16)10; decimal_output[m] = temp;
my_byte = my_byte / (uns16)10; }

for(m++ ; m < 5 ; m++)
putc(bin2Hex(decimal_output[m])); }
else if (k == 'h') //Print Hex
{
//New trick 3-15-04
putc('0');
putc('x');
putc(bin2Hex(my_byte.low8 >> 4)); putc(bin2Hex(my_byte.low8 & 0b.0000.1111));

/*high_byte.3 = my_byte.7;
high_byte.2 = my_byte.6;
high_byte.1 = my_byte.5;
high_byte.0 = my_byte.4;

low_byte.3 = my_byte.3;
low_byte.2 = my_byte.2;
low_byte.1 = my_byte.1;
low_byte.0 = my_byte.0;

putc('0');
putc('x');

putc(bin2Hex(high_byte));
putc(bin2Hex(low_byte));*/ } //End Hex
else if (k == 'f') //Print Float {
putc('!');
} //End Float
else if (k == 'u') //Print Direct Character
{
//All ascii characters below 20 are special and screwy characters //if(my_byte > 20)
putc(my_byte);
} //End Direct

} //End Special Chars

else
putc(k);
}
}

# A.3 SoftTTL.c

# This is written to facilitate bit‐banging TTL‐level serial communications through software. Note that because these are software routines that depend on the current oscillator frequency of the PIC, multiple copies of the same

function must be defined.

/*
7-20-03
Copyright Spark Fun Electronics 2003

Software driven UART Communications - NOT RS232!
Needed for the 16F872 because it has no onboard UART module

*/
//uns8 counter;

//Functions for 4MHz at 9600bps
#ifdef Clock_4MHz

#ifdef Baud_9600

//========================================================================== void soft_TTL_wait(void)
{
int i;
//for(i = 0 ; i < counter ; i++);
//for(i = 0 ; i < 36 ; i++); //Works with 16F872 at 20MHz at 3.3V! - Pre registered compiler for(i = 0 ; i < 12 ; i++); //Checked 10-30-03 = ~104us
}

//Sends out TTL level nate @ 9600 Baud
void soft_TTL_out(uns8 nate)
{

uns8 l;

Soft_Serial_Out = 0;
soft_TTL_wait();

for(l = 0 ; l < 8 ; l++)
{
Soft_Serial_Out = nate.0;
nate = rr(nate);
soft_TTL_wait();
}

Soft_Serial_Out = 1;
delay_us(100); //Hold stop bit for 100us }
//Reads in TTL level signals @ 9600
uns8 soft_TTL_in(void)
{

uns8 j, i, nate, counter = 0;

while (Soft_Serial_In == 1);
//{
// | counter++;
// | if (counter > 245) return(0);
//}

//Pause for 104us during start bit.
//Then pause for ~52us to read middle of first data bit for(i = 0 ; i < 111 ; i++);

for(j = 0 ; j < 8 ; j++)
{
| nate = rr(nate);
| nate.7 = Soft_Serial_In; //Sample the port, should be in middle of the bit
| for(i = 0 ; i < 72 ; i++);
}

return(nate);

}
//========================================================================== #endif
#endif

//End 4MHz and 9600bps

//Functions for 8MHz at 9600bps
#ifdef Clock_8MHz

#ifdef Baud_9600

//==========================================================================

//Sends out TTL level nate @ 9600 Baud
void soft_TTL_out(uns8 nate)
{

uns8 l;

Soft_Serial_Out = 0;
delay_us(22);

for(l = 0 ; l < 8 ; l++)
{
Soft_Serial_Out = nate.0;
nate = rr(nate);
delay_us(21);
}

Soft_Serial_Out = 1;
delay_us(100); //Hold stop bit for 100us }
//Reads in TTL level signals @ 9600
uns8 soft_TTL_in(void)
{

uns8 j, nate, counter = 0;

while (Soft_Serial_In == 1)
{
counter++;
if (counter > 245) return('y');
}

//Pause for 104us during start bit.
//Then pause for ~52us to read middle of first data bit delay_us(30);

for(j = 0 ; j < 8 ; j++)
{
nate = rr(nate);
nate.7 = Soft_Serial_In; //Sample the port, should be in middle of the bit delay_us(21);
}

return(nate);

}
//========================================================================== #endif
#endif

//End 4MHz and 9600bps

//Functions for 8MHz at 57600bps
#ifdef Clock_8MHz

#ifdef Baud_57600

//========================================================================== void soft_TTL_out(uns8 nate)
{

uns8 l, i;

Soft_Serial_Out = 0;
nop();
nop();
//nop();//
for(i = 0 ; i < 3 ; i++); //Pause for ~17.36us

for(l = 0 ; l < 8 ; l++)
{
Soft_Serial_Out = nate.0;
nate = rr(nate);
nop();
nop();
nop();
//nop();//
//nop();//
for(i = 0 ; i < 2 ; i++); //Pause for ~17.36us }

Soft_Serial_Out = 1;
delay_us(100); //Hold stop bit for 100us
//delay_us(3); //Hold stop bit for 100us

}
//========================================================================== #endif
#endif

//End 8MHz and 57600bps

//Functions for 8MHz at 115200bps
#ifdef Clock_8MHz

#ifdef Baud_115200

//==========================================================================

//Sends out TTL levels - nate out at 8MHz 115200 Baud
void soft_TTL_out(uns8 nate)
{
uns8 l, i;

Serial_Out_BB = 0;
for(i = 0 ; i < 1 ; i++); //Pause for ~8.68us

for(l = 0 ; l < 8 ; l++)
{
Serial_Out_BB = nate.0;
nate = rr(nate);
nop(); nop(); nop(); nop(); nop(); //Checked 11-24-03 //nop();//added 1-22
}

Serial_Out_BB = 1;
//delay_us(30); //Hold stop bit for 100us

for(i = 0 ; i < 15 ; i++); //Pause for ~100us //delay_us(3); //Hold stop bit for 100us

}

//Reads in TTL level signals @ 8MHz 115200
uns8 soft_TTL_in(void)
{

uns8 j, i = 0, nate;

//Wait ~500us for start bit, return 0 if none is found while (Serial_In_BB == 1)
{
i++;
if (i > 61) return(0);
}

//Pause for 8.68us during start bit.
//Then pause for ~4.34us to read middle of first data bit //Total 13.02us
for(i = 0 ; i < 1 ; i++);
//nop(); nop(); nop(); nop(); nop(); nop(); nop();

for(j = 0 ; j < 8 ; j++)
{
nate = rr(nate);
nate.7 = Serial_In_BB; //Sample the port, should be in middle of the bit ~8.68us nop(); nop(); nop(); nop(); nop(); nop(); //Checked 11-24-03
}

/*The PIC is now sitting in the middle of the stop bit. It has
~52us before the next start bit of the next transmission is allowed. If you do too much during this time, you may miss the next start bit and corrupt the next incoming byte.*/

return(nate);
}
//========================================================================== #endif
#endif

//End 8MHz and 115200bps

//Functions for 20MHz at 9600bps
#ifdef HS_Osc

#ifdef Baud_9600

//========================================================================== void soft_TTL_wait(void)
{
int i;
for(i = 0 ; i < 56 ; i++); // One of many (53-61) that work fine with new CC5x }

//Sends out TTL levels - nate out at 9600 Baud
void soft_TTL_out(uns8 nate)
{
uns8 l;

Serial_Out_BB = 0;
soft_TTL_wait();

for(l = 0 ; l < 8 ; l++)
{
Serial_Out_BB = nate.0;
nate = rr(nate);
soft_TTL_wait();
}

Serial_Out_BB = 1;
delay_us(100); //Hold stop bit for 100us

}

//Reads in TTL level signals @ 9600
uns8 soft_TTL_in(void)
{

uns8 j, i, nate, counter = 0;

//Wait ~500us for start bit, return 0 if none is found

while (Serial_In_BB == 1)
{
counter++;
if (counter > 245) return('t');
}

//Pause for 104us during start bit.
//Then pause for ~52us to read middle of first data bit for(i = 0 ; i < 111 ; i++);

for(j = 0 ; j < 8 ; j++)
{
nate = rr(nate);
nate.7 = Serial_In_BB; //Sample the port, should be in middle of the bit for(i = 0 ; i < 72 ; i++);
}

/*The PIC is now sitting in the middle of the stop bit. It has
~52us before the next start bit of the next transmission is allowed. If you do too much during this time, you may miss the next start bit and corrupt the next incoming byte.*/

return(nate);
}
//========================================================================== #endif
#endif

//End 20MHz and 9600bps

//Returns ASCII Decimal and Hex values uns8 bin2HexTTL(char x)
{
skip(x);
#pragma return[16] = "0123456789ABCDEF"

}

//Prints a string including variables
void printf_bb_ttl(const char *nate, int16 my_byte) {
//Display byte

uns8 i, k, m, temp;
uns8 high_byte = 0, low_byte = 0; uns8 y, z;

uns8 decimal_output[5];

for(i = 0 ; ; i++)
{
k = nate[i];

if (k == '\0')
break;

else if (k == '%') //Print var {
i++;
k = nate[i];

if (k == '\0')
break;
else if (k == 'b') //Print Binary {
for( m = 0 ; m < 8 ; m++ )
{
if (my_byte.7 == 1) soft_TTL_out('1'); if (my_byte.7 == 0) soft_TTL_out('0');

if (m == 3) soft_TTL_out(' ');

my_byte = my_byte << 1;
}
} //End Binary
else if (k == 'd') //Print Decimal
{
for(m = 4 ; my_byte > 0 && m < 255 ; m--) {
temp = my_byte % (uns16)10; decimal_output[m] = temp;
my_byte = my_byte / (uns16)10;
}

for(m++ ; m < 5 ; m++)
soft_TTL_out(bin2HexTTL(decimal_output[m])); }
else if (k == 'h') //Print Hex
{
high_byte.3 = my_byte.7;
high_byte.2 = my_byte.6;
high_byte.1 = my_byte.5;
high_byte.0 = my_byte.4;

low_byte.3 = my_byte.3;
low_byte.2 = my_byte.2;
low_byte.1 = my_byte.1;

low_byte.0 = my_byte.0;

soft_TTL_out('0');
soft_TTL_out('x');

soft_TTL_out(bin2HexTTL(high_byte)); soft_TTL_out(bin2HexTTL(low_byte)); } //End Hex
else if (k == 'f') //Print Float
{
soft_TTL_out('!');
} //End Float

else if (k == 'u') //Print Direct Character {
//if(my_byte > 20)
soft_TTL_out(my_byte);
} //End Direct

} //End Special Chars

else
soft_TTL_out(k);
}
}

# A.4 Main.c

# This is the main control code that operates the power regulation, cell phone

communications and data acquisition and processing.

/*
1-23-04
Copyright Spark Fun Electronics 2003

Nathan Seidle
nathan.seidle@colorado.edu

Remote Weather Station using the PIC 16F877A

1-23-04 See if we can catch RC time constants to measure an unknown cap
We can accurately measure ~164pF to 1pF using a multimeter as a control and against current known weather conditions.

Vfin = Vint * exp(-t/RC)
Vfin = 1V - (Microchip 16F88 ST threshold, datasheet page 173-D040
Vint = 5.00V - This is actual power supply voltage - charges cap plate to 5V
R = 983,000 Ohms -> Was 814,000 Ohms
C = Unknown capacitance on humidity sensor. Should be 160-205pF (HS1100 datasheet page 2) t = Returned by function in machine cycles (200ns per machine cycle)

C = -t * 500E-9 / ( ln(1/5) * 983000 )
C = t * 3.16434E-13

Adding the LM335A precision temp sensor. Requires calibration and external 5k resistor.

Moving to DS18S20 temp sensor. No calibration, better precision, more complex interface.

1-24-04 Hmm, the 1820 is now working. After 4-5 hours of testing and datasheet reading, the 1-wire protocol makes perfect sense, but I'm not sure what the 'trick' was, in my case...
It works! 70.7F in my room.

Now polling the 1820 for T conversion completion. Timer1 reports
~0x26A1EC instructions = 2,531,820 * .2us = 506.4ms
pass before the temp conversion is complete.

Received Data cable for Sprint TouchPoint 1100 cell phone today. On the cell phone, under setup: incoming calls is set to 'Data'. When the cell phone is called from another line, hyperterminal at 9600bps says 'RING' just like the old modems did! The 'ATA' command for Answer initiates the standard noisy modem connect tones. It seems we now have a fully fuction modem link over cell technology.

3-13-04 Migration to 16F88 on WeBBS v1.0 PCB. Using 4051 multiplexer. Bloader seems to work really well with the 8mhz internal osc and RS232 shift circuit - amazing!

Multiplexor - LSB is Select1, MSB is Select3

The MUX should be left on a channel that does not allow current flow to minimize
power usage. All power_level channels are a bad idea. >30mA

4-10-04 All the timing for the 1-wire protocol had to be tweaked by hand to adjust for the 8MHz interal operation. Timing worked great at 20MHz but at 8MHz, everything had to be increased carefully. It now works.

4-18-04 Trying out the diode drop to 3.3V for the GPRS module interface

*/
#define Baud_9600

#define Clock_8MHz //8MHz internal operations

#include "c:\Pics\c\16F88.h" // device dependent interrupt definitions

#pragma config |= 0x3F10 //Internal RC Oscillator

#pragma origin 4

//Pin definitions
#pragma bit DQ @ PORTA.2

#define FALSE | 0

#define TRUE | 1

#define INPUT | 1

#define OUTPUT 0

#define Select1 | PORTB.7

#define Select2 | PORTB.6

#define Select3 | PORTB.4

#define Cell_TX | PORTB.3

#define Cell_RX | PORTA.3

#define Analog_In | PORTA.0

#define Peripheral_Power | PORTA.1

#define Charge_Control | PORTA.4

#define Analog_In_Direction | TRISA.0

#define Charge_Control_Direction | TRISA.4

#define Soft_Serial_Out | Analog_In

#define Soft_Serial_In | PORTA.7

#define Serial_Out_BB | Analog_In

#define Serial_In_BB | PORTA.7

//End Pin Definitions

//Function definitions
#include "c:\Pics\code\Delay.c" | // Delays

#include "c:\Pics\code\Stdio.c" | // Basic Serial IO

#include "c:\Pics\code\softttl.c" | // Software based Basic Serial IO

#include "c:\Pics\code\soft232.c" | // Software based Basic Serial IO

//#include "c:\Pics\code\i2c.c" | // I2C routines for the eeprom interface
void boot_up(void);

void check_temperature(void);
void check_humidity(void);
void check_pressure(void); void check_power(void);
void check_wind(void);
void check_signal(void);

uns16 read_analog(void);

void dazed_confused(void);

void send_1wire_command(uns8 cmd); uns8 read_1wire_byte(void);
void reset_1wire_bus(void);

void Cell_out(uns8 nate);
uns8 Cell_in(void);
void Cell_power(void);
void printf_Cell(const char *nate, int16 my_byte);

//Global Variables
int16 current_temperature_C;
int16 current_temperature_F;
int16 current_humidity;
int16 current_pressure;
int16 current_battery_level; int16 current_solar_level;

uns8 current_wind_speed[5]; uns8 current_wind_direction[3]; uns8 current_wind_rose[2];

uns8 current_signal_strength[2];

bit Incoming_Call;

uns8 b;
//End Global Variables

void main()
{
uns8 choice, nate, i;

nate = 0;

boot_up();

while(1)
{
nate++;

printf("\n\r\n\rWelcome to the Weather Station BBS v1.1\n\r", 0); printf("============================================\n\r", 0); printf("Main Menu:\n\r", 0);
printf(" 1) Start Monitor\n\r", 0);
printf(" 2) Current Status\n\r", 0);
printf(" 6) Power down peripherals\n\r", 0); printf(" 7) Power up peripherals\n\r", 0); printf(" a) Sleep for 5 sec\n\r", 0); //printf(" d) Power Cycle Cell Phone\n\r", 0); printf(" Nate=%h\n\r", nate);
printf("\n\r : ", 0);

//Set the monitor to start on boot
if(nate != 1)
choice = getc();
else
choice = '1';

if (choice == '1')
{
printf("Starting Monitor\n\r", 0);

while(1)
dazed_confused();
}

else if (choice == '2')
{
printf("Current status...\n\r", 0);

check_humidity(); //Read current humidity printf("Humidity = %d", current_humidity); putc('%');
printf("\n\r", 0);

check_pressure(); //Read current barometric pressure printf("Barometric Pressure in mili bars = %d\n\r", current_pressure);

check_temperature(); //Read one-wire bus to DS18S20 sensors printf("Temp in C = %d\n\r",current_temperature_C);

check_wind();//Check wind

check_power(); //Output current power levels printf("Battery Level = %dV\n\r", current_battery_level); printf("Solar Level = %dV\n\r", current_solar_level);

check_signal();
printf("Signal strength:", 0); putc(current_signal_strength[0]); putc(current_signal_strength[1]);

printf("\n\rWind speed is: ", 0); for(i = 0 ; i < 5 ; i++)
putc(current_wind_speed[i]);

printf("\n\rWind direction is: ", 0); for(i = 0 ; i < 3 ; i++)
putc(current_wind_direction[i]);

printf("\n\rWind rose is: ", 0); for(i = 0 ; i < 2 ; i++)
putc(current_wind_rose[i]);

printf("\n\rPress return...", 0); while(getc() != '\r');

}
else if (choice == '6')
{
printf("P down periphs\n\r", 0);

//Change the Mux connect back to an input Analog_In_Direction = 1; //0 = Output

//Select pressure sensor on the multiplexer Select3 = 0; Select2 = 0; Select1 = 0;

OPTION.7 = 1; //Disable weak pull-ups

Peripheral_Power = 0;
}
else if (choice == '7')
{
printf("P up periphs\n\r", 0);

//Change the Mux connect back to an input Analog_In_Direction = 1; //0 = Output

//Select pressure sensor on the multiplexer Select3 = 1; Select2 = 0; Select1 = 1;

OPTION.7 = 0; //Enable weak pull-ups

Peripheral_Power = 1;
}
else if (choice == 'a')
{
printf("Sleeping for 5 seconds\n\r", 0);
//Tune the internal oscillator
OSCCON = 0b.0000.0000; //Setup internal oscillator for 31.25kHz //while(OSCCON.2 == 0); //Wait for frequency to stabilize

delay_s_lp(5);

//Tune the internal oscillator
OSCCON = 0b.0111.0000; //Setup internal oscillator for 8MHz while(OSCCON.2 == 0); //Wait for frequency to stabilize

printf("Awake\n\r", 0);
}
else if (choice == 'd')
{
printf("Sending hard power signal\n\r", 0);

Cell_power();
}
else if (choice == 'e')
{
uns8 i;

printf_Cell("AT\n\r", 0);

for(i = 0 ; i < 20 ; i++)
putc(Cell_in());
}

else
{
printf("choice = %h", choice); }

}

while(1);

}//End Main

//Initializes the various ports and interrupts
void boot_up(void)
{
//Tune oscillator to try to get better A/D readings OSCTUNE = 0b.0000.0000;

//Tune the internal oscillator
OSCCON = 0b.0111.0000; //Setup internal oscillator for 8MHz while(OSCCON.2 == 0); //Wait for frequency to stabilize

//Setup Ports
CMCON = 0b.0000.0111; //Turn off comparator on RA port ANSEL = 0b.0000.0000; //Turn Port A to digital IO

//Pins:
//RA0 - Analog_In : May be input or output
//RA1 - Power Control : Always output, start with everything off //RA2 - One-Wire Temp : I/O
//RA3 - Cell_RX : Always input
//RA4 - Charge Control : Always Output, Start charging on boot! //RA5 - VPP NC
//RA6 - Humidity Capactitor : I/O
//RA7 - Wind - Receiver : Always input
PORTA = 0b.1111.1101;
TRISA = 0b.1110.1101; //0 = Output 1 = Input

//RB0 - SCL : Always output
//RB1 - SDA : I/O
//RB2 - RX : Input but handled with hardware
//RB3 - Cell_TX : Always output - Held high until transmission begins //RB4 - Select 3 : Always output
//RB5 - TX : Output but handled with hardware
//RB6 - Select 2 : Always Output
//RB7 - Select 1 : Always output
PORTB = 0b.0000.1110;
TRISB = 0b.0000.0110; //0 = Output 1 = Input

OPTION.7 = 0; //Enable weak pull-ups

enable_uart_TX(0);
enable_uart_RX(0);

Peripheral_Power = 1;

}

//This function power cycles (either on or off) the cell module void Cell_power(void)
{
printf("Sending hard power signal\n\r", 0);

Peripheral_Power = 1;
delay_ms(100);

//Select the cell on/off on the MUX - Channel 7 Select3 = 1; Select2 = 1; Select1 = 1;

//Make the Mux connect an output Analog_In_Direction = 0; //0 = Output

//Send a 1 second high pulse Analog_In = 1;
delay_ms(1500);
Analog_In = 0;
delay_ms(1500);

//Return to Channel 0
Select3 = 0; Select2 = 0; Select1 = 0;

//Change the Mux connect back to an input
Analog_In_Direction = 1; //0 = Output
}

//This function checks the signal strength returned by the cell module void check_signal(void)
{
uns8 i;

current_signal_strength[0] = 'X'; current_signal_strength[1] = 'X';

printf_Cell("AT+CSQ\n\r", 0);

//Poll for special returned character for(i = 0 ; i < 20 ; i++)
{
if (Cell_in() == ':')
{
current_signal_strength[0] = Cell_in(); //Catch space
current_signal_strength[0] = Cell_in(); //Catch signal strength 10s or 1s digit current_signal_strength[1] = Cell_in(); //Catch signal strength 1s digit or ','

if (current_signal_strength[1] == ',') current_signal_strength[1] = ' '; //Erase the comma if it is there
}
}

//Output to terminal
//putc(current_signal_strength[0]); //putc(current_signal_strength[1]);

}

//Sends out TTL level nate @ 9600 Baud void Cell_out(uns8 nate)
{

uns8 l;

Cell_TX = 0;
delay_us(20);

for(l = 0 ; l < 8 ; l++)
{
Cell_TX = nate.0;
nate = rr(nate);
delay_us(20);
}

Cell_TX = 1;
delay_us(100); //Hold stop bit for 100us }
//Reads in TTL level signals @ 9600
uns8 Cell_in(void)
{

uns8 j, nate;
uns16 counter = 0;

while (Cell_RX == 1)
{
counter++;
if (counter > 1245) return('z');
}

//Pause for 104us during start bit.
//Then pause for ~52us to read middle of first data bit //for(i = 0 ; i < 111 ; i++);
delay_us(30);

for(j = 0 ; j < 8 ; j++)
{
nate = rr(nate);
nate.7 = Cell_RX; //Sample the port, should be in middle of the bit delay_us(20);
}

return(nate);

}

//Checks the current voltage level on the MPX4115A Pressure sensor void check_pressure(void)
{
uns16 pressure_value;
uns24 mb_pressure;

//Select pressure sensor on the multiplexer
Select3 = 0; Select2 = 0; Select1 = 0;

pressure_value = read_analog();

//Reported value is a number, 0-1023 with 1023 being Vdd. //Pressure = p_v / 9.207 + 10.56 - from MPX4115A datasheet
//Or Pressure * 100 = p_v * 10000 / 9216 + 106
//mili bars is kpa * 10

//Update 4-16-04 : Our Vcc is 4.41V after power control transistor //Pressure = p_v / 9.207 + 10.56
//p_v = analog_reading * Vcc / 1023
//p_v = 574 * 5.1 / 1023 mb_pressure = pressure_value * (uns24)10000; mb_pressure /= 7961;
mb_pressure += 106;

current_pressure = mb_pressure;

//printf("Barometric Pressure in mili bars = %d\n\r", current_pressure);

}

#pragma codepage 1

//Prints a string including variables
void printf_Cell(const char *nate, int16 my_byte) {
//Display byte

uns8 i, k, m, temp;

uns8 decimal_output[5];

for(i = 0 ; ; i++)
{
k = nate[i];

if (k == '\0')
break;

else if (k == '%') //Print var {
i++;
k = nate[i];

if (k == '\0')
break;
else if (k == 'u') //Print Direct Character Cell_out(my_byte);
else if (k == 'd') //Print Decimal
{
//Print negative sign and take 2's compliment if(my_byte < 0)
{
putc('-');
my_byte ^= 0xFFFF;
my_byte++;
}

//Divide number by a series of 10s for(m = 4 ; my_byte > 0 && m < 255 ; m--) {
temp = my_byte % (uns16)10; decimal_output[m] = temp;
my_byte = my_byte / (uns16)10;
}

for(m++ ; m < 5 ; m++)
Cell_out(bin2Hex(decimal_output[m]));

} //End Decimal

} //End Special Chars

else
Cell_out(k);
}
}

//This function does the main processing void dazed_confused(void)
{
uns8 i, j;
uns16 seconds;

//printf("Checking current conditions\n\r", 0);

//Power up peripherals
Peripheral_Power = 1;
OPTION.7 = 0; //Enable weak pull-ups delay_ms(500);

check_humidity(); //Read current humidity check_pressure(); //Read current barometric pressure check_temperature(); //Read one-wire bus to DS18S20 sensors check_wind();//Check wind
check_power(); //Output current power levels check_signal(); //Check cell signal

//Update the LCD display
//Select the LCD on the MUX - Channel 6 Select3 = 1; Select2 = 1; Select1 = 0;

//Make the Mux connect an output Analog_In_Direction = 0; //0 = Output

delay_ms(100);
soft_TTL_out(' ');
delay_ms(100);
soft_TTL_out(' ');
delay_ms(100);
soft_TTL_out(124);
soft_TTL_out(8); //Re-init LCD delay_ms(100);
soft_TTL_out(254);
soft_TTL_out(1); //Clear screen delay_ms(4000);

for(seconds = 10 ; seconds > 0 ; ) {

for(j = 0 ; j < 5 ; j++)
{
soft_TTL_out(254);
soft_TTL_out(1); //Clear screen
delay_ms(1);

printf_bb_ttl("T:%d ", current_temperature_C); printf_bb_ttl("H:%d", current_humidity); soft_TTL_out('%');
printf_bb_ttl(" P:%d", current_pressure); printf_bb_ttl("B:%dmV ", current_battery_level);

//Pause for 5 seconds
printf_bb_ttl(" %d", --seconds); delay_ms(1000);
}

for(j = 0 ; j < 5 ; j++)
{
//Erase screen
soft_TTL_out(254);
soft_TTL_out(1); //Clear screen delay_ms(1);

printf_bb_ttl("WS:", 0);
for(i = 0 ; i < 5 ; i++)
soft_TTL_out(current_wind_speed[i]);

printf_bb_ttl(" WD:", 0);
for(i = 0 ; i < 3 ; i++)
soft_TTL_out(current_wind_direction[i]);

//printf_bb_ttl(" WR:", 0);
//for(i = 0 ; i < 2 ; i++)
// soft_TTL_out(current_wind_rose[i]);

check_signal(); //Check cell signal

printf_bb_ttl(" CSS:", 0);
for(i = 0 ; i < 2 ; i++)
soft_TTL_out(current_signal_strength[i]);
printf_bb_ttl(" | %d", --seconds);
delay_ms(1000);
}
}

//Power on cell module
soft_TTL_out(254);
soft_TTL_out(1); //Clear screen
delay_ms(10);
printf_bb_ttl("Powering cell | module | ", 0);

while(Cell_RX == 0)
{
Cell_power(); //Power up cell module delay_ms(5000);
}

soft_TTL_out(254);
soft_TTL_out(1); //Clear screen delay_ms(1);
printf_bb_ttl("Cell is ON", 0); delay_ms(5000);

//Now poll until signal is available for(j = 0 ; j < 15 ; j++)
{
check_signal();

soft_TTL_out(254);
soft_TTL_out(1); //Clear screen
delay_ms(1);
printf_bb_ttl("Signal Level: %u", current_signal_strength[0]); printf_bb_ttl("%u", current_signal_strength[1]); printf("Waiting for signal\n\r", 0);

delay_ms(5000);

if(current_signal_strength[1] == '9' || current_signal_strength[1] == 'X') {
//if(current_signal_strength[0] != '9') break;
//No signal, keep going
}
else
break;
}

if(j == 15)
{
soft_TTL_out(254);
soft_TTL_out(1); //Clear screen delay_ms(1);
printf_bb_ttl("Call failed", 0); delay_ms(3000);
//return;
}

soft_TTL_out(254);
soft_TTL_out(1); //Clear screen delay_ms(1);
printf_bb_ttl("Placing call to base", 0); delay_ms(2000);

//Call josh's house

// printf_Cell("ATD 3034445579\n\r", 0);

delay_ms(50000); //20 Seconds for connection
/*
printf_Cell("weather ============================\n\r", 0); printf_Cell("weather Temperature = %dC\n\r", current_temperature_C); printf_Cell("weather Humidity = %d\n\r", current_humidity); printf_Cell("weather Pressure = %dmiliBar\n\r", current_pressure);

printf_Cell("weather Wind Speed = ", 0);
for(i = 0 ; i < 5 ; i++)
Cell_out(current_wind_speed[i]);
printf_Cell("\n\r", 0);

printf_Cell("weather Wind Direction = ", 0); for(i = 0 ; i < 3 ; i++)
Cell_out(current_wind_direction[i]);
printf_Cell("\n\r", 0);

printf_Cell("weather Signal Strength = %d Bars\n\r", current_signal_strength); printf_Cell("weather Battery Voltage = %dmV\n\r", current_battery_level); printf_Cell("weather Solar Voltage = %dmV\n\r", current_solar_level); printf_Cell("weather ============================\n\r", 0);
*/

printf("weather ============================\n\r", 0); printf("weather Temperature = %dC\n\r", current_temperature_C); printf("weather Humidity = %d\n\r", current_humidity); printf("weather Pressure = %dmiliBar\n\r", current_pressure);

printf("weather Wind Speed = ", 0);
for(i = 0 ; i < 5 ; i++)
putc(current_wind_speed[i]);
printf("\n\r", 0);

printf("weather Wind Direction = ", 0); for(i = 0 ; i < 3 ; i++)
putc(current_wind_direction[i]);
printf("\n\r", 0);

printf("weather Signal Strength = %d Bars\n\r", current_signal_strength); printf("weather Battery Voltage = %dmV\n\r", current_battery_level); printf("weather Solar Voltage = %dmV\n\r", current_solar_level); printf("weather ============================\n\r", 0);
/*

printf("weather ============================\n\r", 0); printf("weather Temperature = %dC\n\r", current_temperature_C); printf("weather Humidity = %d\n\r", current_humidity); printf("weather Pressure = %dmiliBar\n\r", current_pressure); printf("weather Battery Voltage = %dV\n\r", current_battery_level); printf("weather ============================\n\r", 0);

delay_ms(3000);
*/

//Hangup phone by turning off cell module soft_TTL_out(254);
soft_TTL_out(1); //Clear screen delay_ms(1);
printf_bb_ttl("Powering down cell", 0); printf("Powering down cell\n\r", 0); while(Cell_RX == 1)
{
Cell_power();
delay_ms(10000);
}

soft_TTL_out(254);
soft_TTL_out(1); //Clear screen
delay_ms(1);
printf_bb_ttl("Update complete! Going to low power mode", 0); delay_ms(2000);

//Change the Mux connect back to an input Analog_In_Direction = 1; //0 = Output

//Select pressure sensor on the multiplexer Select3 = 0; Select2 = 0; Select1 = 0;

OPTION.7 = 1; //Disable weak pull-ups

Peripheral_Power = 0;

printf("Low power mode\n\r", 0);
//Tune the internal oscillator
OSCCON = 0b.0000.0000; //Setup internal oscillator for 31.25kHz //while(OSCCON.2 == 0); //Wait for frequency to stabilize

delay_s_lp(350);

//Tune the internal oscillator
OSCCON = 0b.0111.0000; //Setup internal oscillator for 8MHz while(OSCCON.2 == 0); //Wait for frequency to stabilize

printf("8MHz mode\n\r", 0);

}

//Powers the wind sensor and listens for the incoming wind speed //and direction
//looks like:
//$$$SSS.SS00DDDaa$$
//Wind sensor TX in located on RA7 void check_wind(void)
{
uns8 i;

current_wind_speed[0] = '0'; current_wind_speed[1] = '0'; current_wind_speed[2] = '0'; current_wind_speed[3] = '0';
current_wind_speed[4] = '0';
current_wind_direction[0] = '0';
current_wind_direction[1] = '0'; //10s digit of direction angle current_wind_direction[2] = '0'; //1s digit of direction angle current_wind_rose[0] = '0'; //Rose direction 'N' or '-', etc current_wind_rose[1] = '0'; //Rose direction 'S' or 'E', etc

//Wait for three incoming $'s
for(i = 0 ; i < 200 ; i++)
if(soft_TTL_in() == '$') break;
for(i = 0 ; i < 200 ; i++) if(soft_TTL_in() == '$') break; for(i = 0 ; i < 200 ; i++)
if(soft_TTL_in() == '$') break;

//Begin recording
current_wind_speed[0] = soft_TTL_in(); //This is fake, first number is always 0 current_wind_speed[0] = soft_TTL_in(); //10s digit
current_wind_speed[1] = soft_TTL_in(); //1s digit
current_wind_speed[2] = soft_TTL_in(); //Should be '.'
current_wind_speed[3] = soft_TTL_in(); //.1's digit current_wind_speed[4] = soft_TTL_in(); //.01's digit

current_wind_direction[0] = soft_TTL_in(); //Filler 0 current_wind_direction[0] = soft_TTL_in(); //Filler 0 current_wind_direction[0] = soft_TTL_in(); //100s digit of direction angle current_wind_direction[1] = soft_TTL_in(); //10s digit of direction angle current_wind_direction[2] = soft_TTL_in(); //1s digit of direction angle

current_wind_rose[0] = soft_TTL_in(); //Rose direction 'N' or '-', etc current_wind_rose[1] = soft_TTL_in(); //Rose direction 'S' or 'E', etc

}

//Charges the variable capacitor humidity sensor
//Returns machine cycles, 200us each.
void check_humidity(void)
{
uns24 cap_size;

//Setup port to charge cap
PORTA.6 = 1;
TRISA.6 = 0; //0 = Output, 1 = Input

delay_ms(3); //Charge cap

TMR1H = 0; TMR1L = 0; //Clear timer1

TRISA.6 = 1; //0 = Output, 1 = Input

TMR1ON = 1; //Start timing while(PORTA.6 == 1);
TMR1ON = 0; //Stop timing

cap_size.high8 = 0;
cap_size.mid8 = TMR1H;
cap_size.low8 = TMR1L;

//printf("Humidity Timer = %d\n\r", cap_size);

//The capsize was measured and calibrated against the timer value cap_size *= (uns24)316;
cap_size /= 1000;
cap_size += 50; //Adjust for 50pF of pin capacitance

//printf("Humidity Sensor = %dpF\n\r", cap_size);

current_humidity = 5;
if(cap_size > 166) current_humidity = 10; if(cap_size > 168) current_humidity = 15; if(cap_size > 170) current_humidity = 20; if(cap_size > 172) current_humidity = 25; if(cap_size > 173) current_humidity = 30; if(cap_size > 174) current_humidity = 35; if(cap_size > 176) current_humidity = 40; if(cap_size > 178) current_humidity = 45; if(cap_size > 179) current_humidity = 50; if(cap_size > 182) current_humidity = 55; if(cap_size > 183) current_humidity = 60; if(cap_size > 184) current_humidity = 65; if(cap_size > 186) current_humidity = 70; if(cap_size > 188) current_humidity = 75; if(cap_size > 191) current_humidity = 80; if(cap_size > 193) current_humidity = 85; if(cap_size > 195) current_humidity = 90; if(cap_size > 198) current_humidity = 95; if(cap_size > 200) current_humidity = 100;

//printf("Humidity = %d", current_humidity); //putc('%');
//printf("\n\r", 0);
}

//Checks the current voltage on the 2.5V Reference void check_power(void)
{

uns16 power_status[5];
uns8 i;
uns24 power_level;
uns16 vref;

//The MUX is power controlled - checking anything attached, we must power MUX //Peripheral_Power = 1;
//delay_ms(100);

//Select 001 for 2.5V Reference
Select3 = 0; Select2 = 0; Select1 = 1; power_status[0] = read_analog();

//Select 010 for Power Level 1 - Solar current 1 Select3 = 0; Select2 = 1; Select1 = 0; power_status[1] = read_analog();

//Select 011 for Power Level 2 - Battery Level
Select3 = 0; Select2 = 1; Select1 = 1;
power_status[2] = read_analog();

//Select 100 for Power Level 3 - Circuit current usage 1 Select3 = 1; Select2 = 0; Select1 = 0;
power_status[3] = read_analog();

//Select 101 for Power Level 4 - Solar Voltage
//We have to stop driving Charge_Control if we want to see the voltage!

//Revision 2 PCB
Charge_Control_Direction = INPUT;
Select3 = 1; Select2 = 0; Select1 = 1;
power_status[4] = read_analog(); Charge_Control_Direction = OUTPUT;

vref = power_status[0];

power_level = power_status[2]; power_level *= (uns16)250;
power_level /= (uns16)vref;
power_level *= (uns16)314; current_battery_level = power_level / 10;

power_level = power_status[4]; power_level *= (uns16)250;
power_level /= (uns16)vref;
power_level *= (uns16)314; current_solar_level = power_level / 10;

printf("\n\r", 0);
printf("Power Array = Vref | Pre-Batt | Batt Lvl | Circ Draw Solar Lvl", 0);

printf("\n\r", 0);
printf("Power Array = ", 0);
for(i = 0 ; i < 5 ; i++)
{
power_level = power_status[i];

printf("%h-", power_level.mid8);
printf("%h ", power_level.low8);
}

//Calculate out the various voltages based on the Vref(2.5V) reading vref = power_status[0];
//Voltage = p_status[x] * 250 / vref
//Example:
//Voltage = 394 * 250 / 514 = 191.6 = 1.91V

printf("\n\r", 0);
printf("Power Array = ", 0);
for(i = 0 ; i < 5 ; i++)
{
power_level = power_status[i]; power_level *= 250;
power_level /= vref;
//print_decimal(power_level, 2); printf("V ", 0);
}

}

//Communicates with DS18S20 1-wire digital temp sensor void check_temperature(void)
{
uns8 i, temp;
uns8 temperature_array[10];

reset_1wire_bus(); //Reset bus
send_1wire_command(0xCC); //Send out Skip ROM command send_1wire_command(0x44); //Tell sensor to get temperature //This can take as much as 750ms - nominally 506ms //Wait for a 1 response
while(read_1wire_byte() == 0);

reset_1wire_bus(); //Reset bus
send_1wire_command(0xCC); //Send out Skip ROM command send_1wire_command(0xBE); //Read the scratch pad - ie the temperature bytes

for(i = 0 ; i < 9 ; i++)
{
temp = read_1wire_byte();
temperature_array[i] = temp;
}

current_temperature_C = temperature_array[0]; current_temperature_C >>= 1;

//printf("Temp in C = %d\n\r",current_temperature_C);

//for(i = 0 ; i < 9 ; i++)
// printf("%h-",temperature_array[i]); //printf("\n\r",0);

}

//Resets all slaves on the 1wire bus void reset_1wire_bus(void)
{
//Low for min 480us
TRISA.2 = 0; //Output a zero reset pulse length DQ = 0;
delay_ms(1);

//Read in response
TRISA.2 = 1;
delay_us(13); //Actually originally delay_us(60); while(DQ == 0);

}

//Sends out a command serially across 1 wire bus void send_1wire_command(uns8 cmd)
{
//Data is sent out LSB first
uns8 i;

for(i = 0 ; i < 8 ; i++)
{
| TRISA.2 = 0; //Output 0 DQ = 0; delay_us(1); //Actually originally delay_us(5);

if(cmd.0 == 0) TRISA.2 = 0; //Continue 0 output if(cmd.0 == 1) TRISA.2 = 1; //Release and let line rise delay_us(13); //Actually originally delay_us(60);

TRISA.2 = 1; //Release port before next slot delay_us(1); //Actually originally delay_us(5);

cmd = cmd >> 1; //Rotate to next data bit
}

}

//Serially reads the current byte from 11 wire bus uns8 read_1wire_byte(void)
{
//Data is received LSB first
uns8 i, data_in;

for(i = 0 ; i < 8 ; i++)
{
TRISA.2 = 0; //Output a zero to signal slot DQ = 0;
//delay_us(3); //Hold a minimum of 1us
nop2(); nop2();

TRISA.2 = 1; //Release line for DS18S20 take over delay_us(1); //Actually originally delay_us(5);

data_in = data_in >> 1;
data_in.7 = DQ; //Read the data bus

delay_us(10); //Originally delay_us(55); //Wait for minimum of 45us for next slot }

return(data_in);
}

//Reads the Analog level off port_num 0-7 - returns the raw voltage level uns16 read_analog(void)
{
uns16 temp;

//Read Channel port_num - for Analog voltage
TRISA = TRISA | 0b.0000.0001; //0 = Output, 1 = Input

//Select analog port # - Only on 16F88
ANSEL = 0b.0000.0001;

//ADCON0 = 0b.0100.0001; //Select Fosc/16 for 8mhz, and channel RA0/AN0, A/D on
//ADCON1 = 0b.1100.0000; //Setup ADC for right justified with all AN ports as Analog ADCS2 = 1 ADCON0 = 0b.1000.0001; //Select Fosc/16 for 8mhz, and channel RA0/AN0, A/D on
ADCON1 = 0b.1000.0000; //Setup ADC for right justified with all AN ports as Analog ADCS2 = 1

delay_ms(5);

GO = 1; //Convert RA0 to digital

while(GO == 1);

temp.high8 = ADRESH;
temp.low8 = ADRESL;

return(temp);
}

# Appendix B: Main Board Schematics and PCB

# This appendix has circuit layout information for the main board of the WeBBS

weather station.

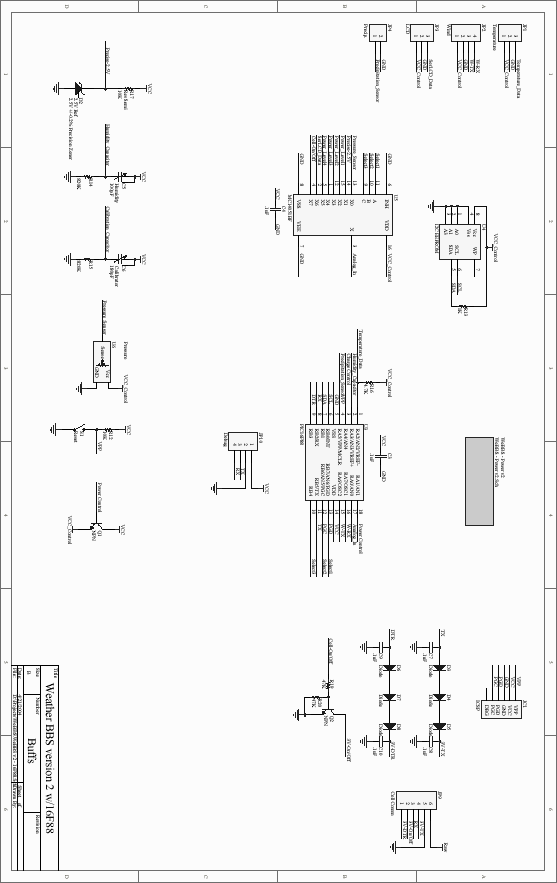
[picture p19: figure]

# Figure 22: Main Board Schematic

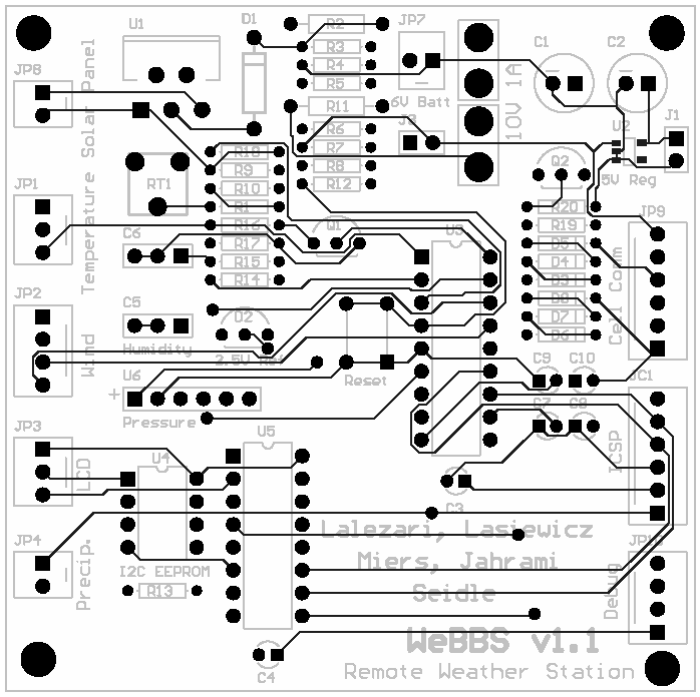
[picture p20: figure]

# Figure 23: Main Board PCB

# Appendix C: Communications Schematics and PCB

# This appendix has circuit layout information for the communications board of

the WeBBS weather station.

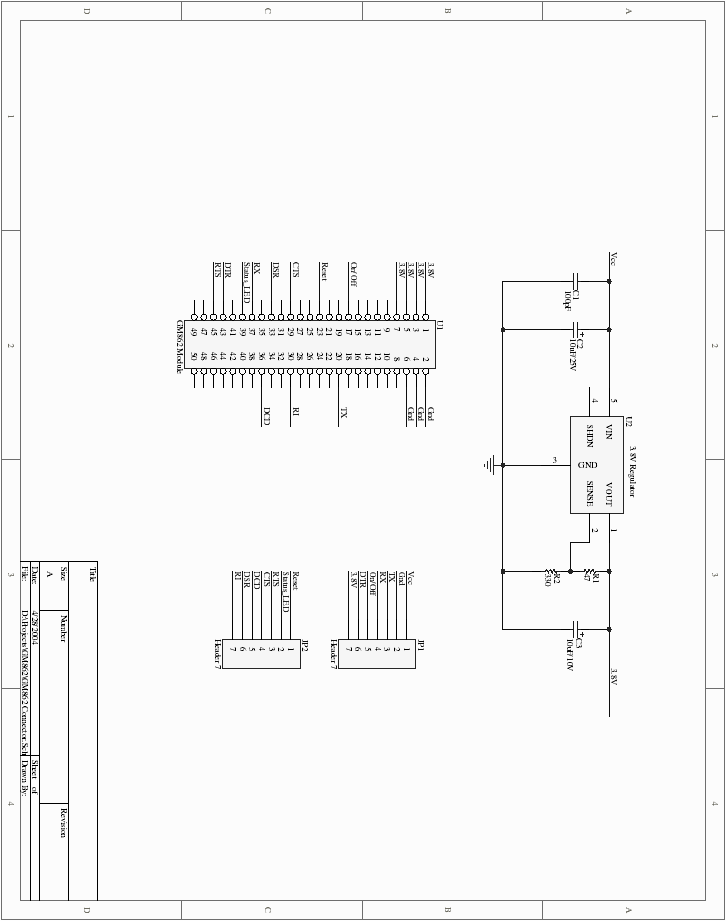
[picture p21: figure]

# Figure 24: Communications Board Schematic

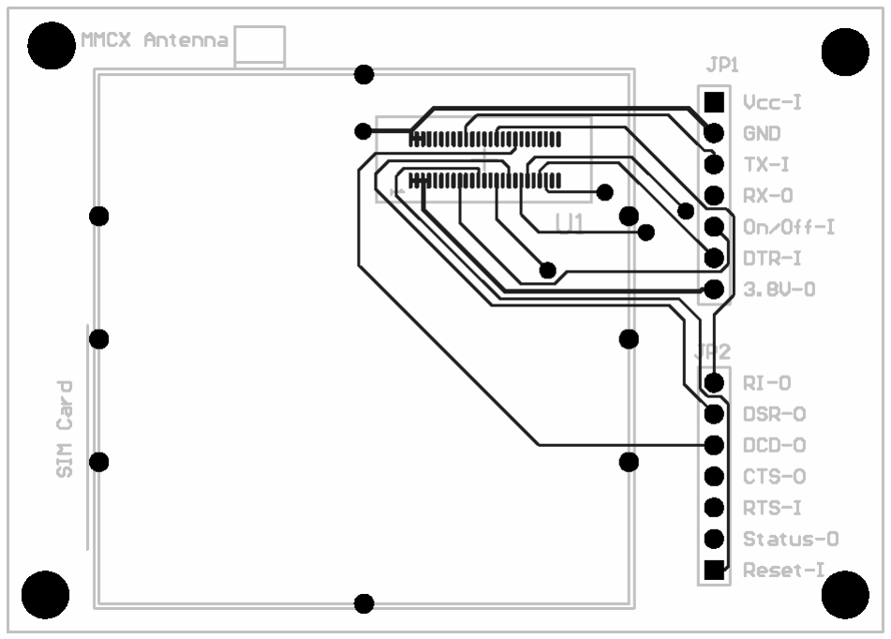
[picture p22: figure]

# Figure 25: Communications Board PCB

# Appendix D: Wind Board Schematics and PCB

# This appendix has circuit layout information for the anemometer board of the

WeBBS weather station.

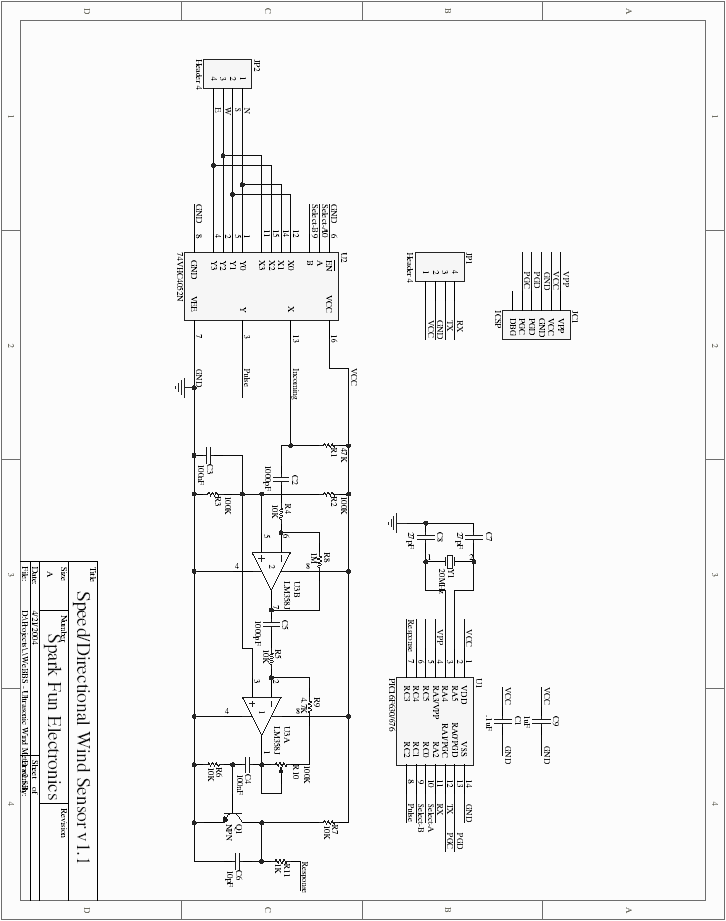
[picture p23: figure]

# Figure 26: Wind Sensor Schematic

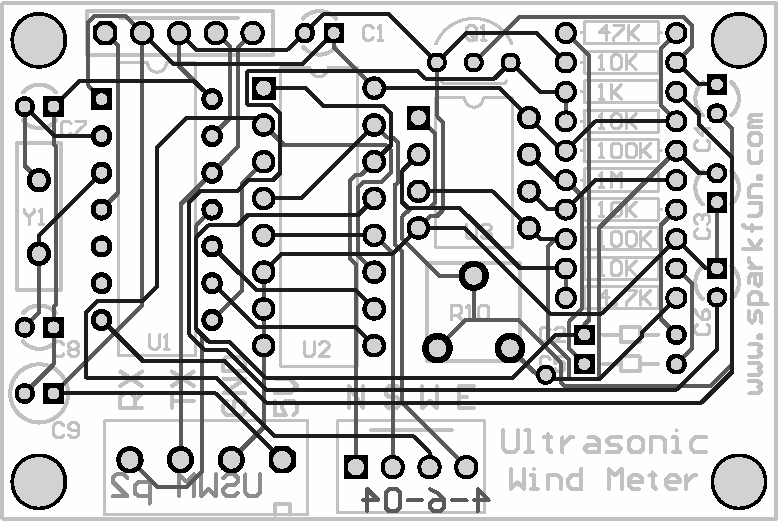
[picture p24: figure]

# Figure 27: Wind Sensor PCB

# Appendix E: Wind Microcontroller Code

# This appendix contains annotated code used to process information from the

ultrasonic anemometer on the WeBBS weather station.

# E.1 Soft232.c

# This is written to facilitate bit‐banging serial RS232‐level serial communications through software. Note that because these are software routines that depend on the current oscillator frequency of the PIC, multiple

copies of the same function must be defined.

/*
7-20-03
Copyright Spark Fun Electronics 2003

Software driven RS232
Needed for the 16F872 because it has no onboard UART module

10-12-03 Overhauled. Everything has been gone over with a fine toothed comb. Timing and logic should all check out. Functions preform very well.

11-6-03 First time at 8MHz with 57600 - no problems!
11-24-03 115200 @ 8MHz - Works.

*/
//uns8 counter;

//Functions for 20MHz at 9600bps
#ifdef HS_Osc

#ifdef Baud_9600

//========================================================================== void soft_rs232_wait(void)
{
int i;
for(i = 0 ; i < 56 ; i++); // One of many (53-61) that work fine with new CC5x }

//Sends out RS232 levels - nate out at 9600 Baud
void soft_rs232_out(uns8 nate)
{
uns8 l;

Serial_Out_BB = 1;
soft_rs232_wait();

for(l = 0 ; l < 8 ; l++)
{
Serial_Out_BB = !nate.0;
nate = rr(nate);
soft_rs232_wait();
}

Serial_Out_BB = 0;
delay_us(100); //Hold stop bit for 100us

}

//Reads in RS232 level signals @ 9600
uns8 soft_rs232_in(void)
{

uns8 j, i, nate, counter = 0;

//Wait ~500us for start bit, return 0 if none is found while (Serial_In_BB == 0)
{
counter++;
if (counter > 245) return(0);
}

//Pause for 104us during start bit.
//Then pause for ~52us to read middle of first data bit for(i = 0 ; i < 111 ; i++);
//for(i = 0 ; i < 101 ; i++); //Worked with 16F630 @ 20MHz

for(j = 0 ; j < 8 ; j++)
{
nate = rr(nate);
nate.7 = !Serial_In_BB; //Sample the port, should be in middle of the bit for(i = 0 ; i < 72 ; i++);

}

/*The PIC is now sitting in the middle of the stop bit. It has ~52us before the next start bit of the next transmission is allowed. If you do too much during this time, you may miss the next start bit and corrupt the next incoming byte.*/

return(nate);
}
//========================================================================== #endif
#endif

//End 20MHz and 9600bps

//Functions for 4MHz at 9600bps
#ifdef Clock_4MHz

#ifdef Baud_9600

//========================================================================== void soft_rs232_wait(void)
{
int i;
for(i = 0 ; i < 9 ; i++); //Checked 10-30-03 = ~104us nop();
}

//Sends out RS232 levels - nate out at 4MHz 9600 Baud void soft_rs232_out(uns8 nate)
{
uns8 l;

Serial_Out_BB = 1;
soft_rs232_wait();

for(l = 0 ; l < 8 ; l++)
{
Serial_Out_BB = !nate.0;
nate = rr(nate);
soft_rs232_wait();
}

Serial_Out_BB = 0;
delay_us(100); //Hold stop bit for 100us

}

//Reads in RS232 level signals @ 4MHz 9600 //Timing set on 10-31-03
uns8 soft_rs232_in(void)
{

uns8 j, i = 0, nate;

//Wait ~500us for start bit, return 0 if none is found //while (Serial_In_BB == 0);
//{
// | i++;
| //if (i > 61) return('q');
// | if (i == 254) return('q');
//}

//Pause for 104us during start bit.
//Then pause for ~52us to read middle of first data bit for(i = 0 ; i < 20 ; i++);

for(j = 0 ; j < 8 ; j++)
{
| nate = rr(nate);
| nate.7 = !Serial_In_BB; //Sample the port, should be in middle of the bit
| for(i = 0 ; i < 13 ; i++);
| //nop(); nop(); nop(); //Clocks out to 104us between each bit
}

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

return(nate);
}
//========================================================================== #endif
#endif

//End 4MHz and 9600bps

//Functions for 4MHz at 57600bps
#ifdef Clock_4MHz

#ifdef Baud_57600

//========================================================================== void soft_rs232_wait(void)
{
int i;
for(i = 0 ; i < 3 ; i++); //Checked 11-6-03 = ~17.36us

}

//Sends out RS232 levels - nate out at 4MHz 57600 Baud void soft_rs232_out(uns8 nate)
{
uns8 l, i;

Serial_Out_BB = 1;
nop(); nop(); //nop();//
for(i = 0 ; i < 3 ; i++); //Pause for ~17.36us

for(l = 0 ; l < 8 ; l++)
{
Serial_Out_BB = !nate.0;
nate = rr(nate);
nop(); nop(); nop(); //nop();//nop();
for(i = 0 ; i < 2 ; i++); //Pause for ~17.36us }

Serial_Out_BB = 0;
delay_us(100); //Hold stop bit for 100us

}

//Reads in RS232 level signals @ 4MHz 57600 uns8 soft_rs232_in(void)
{

uns8 j, i, nate;
uns16 counter = 0;

//Wait ? for start bit, return 0 if none is found while (Serial_In_BB == 0);
//{
// | counter++;
// | if (counter > 245) return(0);
//}

//Pause for 17.36us during start bit.
//Then pause for ~8.68us to read middle of first data bit //Total 26.08us
for(i = 0 ; i < 5 ; i++);
nop(); nop(); nop(); nop(); nop();

for(j = 0 ; j < 7 ; j++)
{
| nate = rr(nate);
| nate.7 = !Serial_In_BB; //Sample the port, should be in middle of the bit ~17.5us
| nop(); nop(); nop(); nop();
| for(i = 0 ; i < 2 ; i++); //Pause for ~17.36us
}

nate = rr(nate);
nate.7 = !Serial_In_BB; //Sample the port, should be in middle of the bit ~17.5us

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

return(nate);
}
//========================================================================== #endif
#endif

//End 4MHz and 57600bps

//Functions for 8MHz at 9600bps
#ifdef Clock_8MHz

#ifdef Baud_9600

//==========================================================================

//Sends out RS232 levels - nate out at 8MHz 9600 Baud
void soft_rs232_out(uns8 nate)
{
//Fully working 12-26-03
uns8 l, i;

Serial_Out_BB = 1;
for(i = 0 ; i < 27 ; i++); //Pause for ~104us

for(l = 0 ; l < 8 ; l++)
{
| Serial_Out_BB = !nate.0;
| nate = rr(nate);
| for(i = 0 ; i < 28 ; i++); //Pause for ~104us
}

Serial_Out_BB = 0;
for(i = 0 ; i < 35 ; i++); //Hold stop bit for ~108us

}

//Reads in RS232 level signals @ 8MHz 9600
uns8 soft_rs232_in(void)

{

uns8 j, i, nate;
//uns16 counter = 0;

//Wait ? for start bit, return 0 if none is found while (Serial_In_BB == 0);
//{
// | counter++;
// | if (counter > 245) return(0);
//}

//Pause for 104us during start bit.
//Then pause for 52us to read middle of first data bit //Total 156us
for(i = 0 ; i < 43 ; i++);

for(j = 0 ; j < 8 ; j++)
{
| nate = rr(nate);
| nate.7 = !Serial_In_BB; //Sample the port, should be in middle of the bit ~104us
| for(i = 0 ; i < 28 ; i++); //Pause for ~104us
}

return(nate);
}
//========================================================================== #endif
#endif

//End 8MHz and 9600bps

//Functions for 8MHz at 19200bps
#ifdef Clock_8MHz

#ifdef Baud_19200

//==========================================================================

//Sends out RS232 levels - nate out at 8MHz 19200 Baud
void soft_rs232_out(uns8 nate)
{
//Fully working 12-26-03
uns8 l, i;

Serial_Out_BB = 1;
for(i = 0 ; i < 13 ; i++); //Pause for ~52us

for(l = 0 ; l < 8 ; l++)
{
| Serial_Out_BB = !nate.0;
| nate = rr(nate);
| for(i = 0 ; i < 12 ; i++); //Pause for ~52us
}

Serial_Out_BB = 0;
for(i = 0 ; i < 170 ; i++); //Hold stop bit for ~108us

}

//Reads in RS232 level signals @ 8MHz 19200
uns8 soft_rs232_in(void)
{

uns8 j, i, nate;
//uns16 counter = 0;

//Wait ? for start bit, return 0 if none is found while (Serial_In_BB == 0);
//{
// | counter++;
// | if (counter > 245) return(0);
//}

//Pause for 104us during start bit.
//Then pause for 52us to read middle of first data bit //Total 156us
for(i = 0 ; i < 43 ; i++);

for(j = 0 ; j < 8 ; j++)
{
| nate = rr(nate);
| nate.7 = !Serial_In_BB; //Sample the port, should be in middle of the bit ~104us
| for(i = 0 ; i < 28 ; i++); //Pause for ~104us
}

return(nate);
}
//========================================================================== #endif
#endif

//End 8MHz and 19200bps

//Functions for 8MHz at 57600bps #ifdef Clock_8MHz
#ifdef Baud_57600

//==========================================================================

//Sends out RS232 levels - nate out at 8MHz 57600 Baud
void soft_rs232_out(uns8 nate)
{
uns8 l, i;

Serial_Out_BB = 1;
nop(); nop(); nop();//
for(i = 0 ; i < 3 ; i++); //Pause for ~17.36us

for(l = 0 ; l < 8 ; l++)
{
Serial_Out_BB = !nate.0;
nate = rr(nate);
nop(); nop(); nop(); nop();//nop();
for(i = 0 ; i < 2 ; i++); //Pause for ~17.36us }

Serial_Out_BB = 0;
delay_us(100); //Hold stop bit for 100us

}

//Reads in RS232 level signals @ 8MHz 57600 uns8 soft_rs232_in(void)
{

uns8 j, i, nate;
//uns16 counter = 0;

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

//Pause for 17.36us during start bit.
//Then pause for ~8.68us to read middle of first data bit //Total 26.08us
for(i = 0 ; i < 5 ; i++);
nop(); nop(); nop(); nop(); //nop();

for(j = 0 ; j < 7 ; j++)
{
| nate = rr(nate);
| nate.7 = !Serial_In_BB; //Sample the port, should be in middle of the bit ~17.5us
| nop(); nop(); nop(); //nop();
| for(i = 0 ; i < 2 ; i++); //Pause for ~17.36us
}

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

return(nate);
}
//========================================================================== #endif
#endif

//End 8MHz and 57600bps

//Functions for 8MHz at 115200bps
#ifdef Clock_8MHz

#ifdef Baud_115200

//========================================================================== void soft_rs232_wait(void)
{
int i;
for(i = 0 ; i < 3 ; i++); //Checked ? = ~8.68us

}

//Sends out RS232 levels - nate out at 8MHz 115200 Baud void soft_rs232_out(uns8 nate)
{
uns8 l, i;

Serial_Out_BB = 1;

//Original 2-3-04
//for(i = 0 ; i < 1 ; i++); //Pause for ~8.68us //Testing
nop(); nop(); nop(); nop(); nop();
nop(); nop(); nop(); nop(); nop();
nop(); nop(); nop(); nop(); nop();

for(l = 0 ; l < 8 ; l++)
{

Serial_Out_BB = !nate.0;
nate = rr(nate);
nop(); nop(); nop(); nop(); nop(); //Checked 11-24-03 //nop();//added 1-22
}

Serial_Out_BB = 0;
delay_us(30); //Hold stop bit for 100us

//delay_us(3)1-22; //Hold stop bit for 100us

}

//Reads in RS232 level signals @ 8MHz 115200 uns8 soft_rs232_in(void)
{

uns8 j, i = 0, nate;

//Wait ~500us for start bit, return 0 if none is found while (Serial_In_BB == 0)
{
i++;
if (i > 61) return(0);
}

//Pause for 8.68us during start bit.
//Then pause for ~4.34us to read middle of first data bit //Total 13.02us
for(i = 0 ; i < 1 ; i++);
//nop(); nop(); nop(); nop(); nop(); nop(); nop();

for(j = 0 ; j < 8 ; j++)
{
nate = rr(nate);
nate.7 = !Serial_In_BB; //Sample the port, should be in middle of the bit ~8.68us nop(); nop(); nop(); nop(); nop(); nop(); //Checked 11-24-03
}

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

return(nate);
}
//========================================================================== #endif
#endif

//End 8MHz and 115200bps

//Returns ASCII Decimal and Hex values uns8 bin2Hex_2(char x)
{
skip(x);
#pragma return[16] = "0123456789ABCDEF"

}

//Prints a string including variables
void printf_bb(const char *nate, uns8 my_byte) {
//Display byte

uns8 i, k, m;
uns8 high_byte = 0, low_byte = 0; uns8 y, z;

for(i = 0 ; ; i++)
{
k = nate[i];

if (k == '\0')
break;

else if (k == '%') //Print var {
i++;
k = nate[i];

if (k == '\0')
break;
else if (k == 'b') //Print Binary {
for( m = 0 ; m < 8 ; m++ )
{
if (my_byte.7 == 1) soft_rs232_out('1'); if (my_byte.7 == 0) soft_rs232_out('0');

if (m == 3) soft_rs232_out(' ');

my_byte = my_byte << 1;
}
} //End Binary else if (k == 'h') //Print Hex
{
//New trick 3-15-04
soft_rs232_out(bin2Hex_2(my_byte >> 4)); soft_rs232_out(bin2Hex_2(my_byte & 0b.0000.1111));

/*high_byte.3 = my_byte.7;
high_byte.2 = my_byte.6;
high_byte.1 = my_byte.5;
high_byte.0 = my_byte.4;

low_byte.3 = my_byte.3;
low_byte.2 = my_byte.2;
low_byte.1 = my_byte.1;
low_byte.0 = my_byte.0;

soft_rs232_out('0');
soft_rs232_out('x');

soft_rs232_out(bin2Hex(high_byte)); soft_rs232_out(bin2Hex(low_byte));*/ } //End Hex
else if (k == 'f') //Print Float
{
soft_rs232_out('!');
} //End Float

else if (k == 'u') //Print Direct Character {
if(my_byte > 20) soft_rs232_out(my_byte); } //End Direct

} //End Special Chars

else
soft_rs232_out(k);
}
}

# E.2 UltrasonicWindMeter.c
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

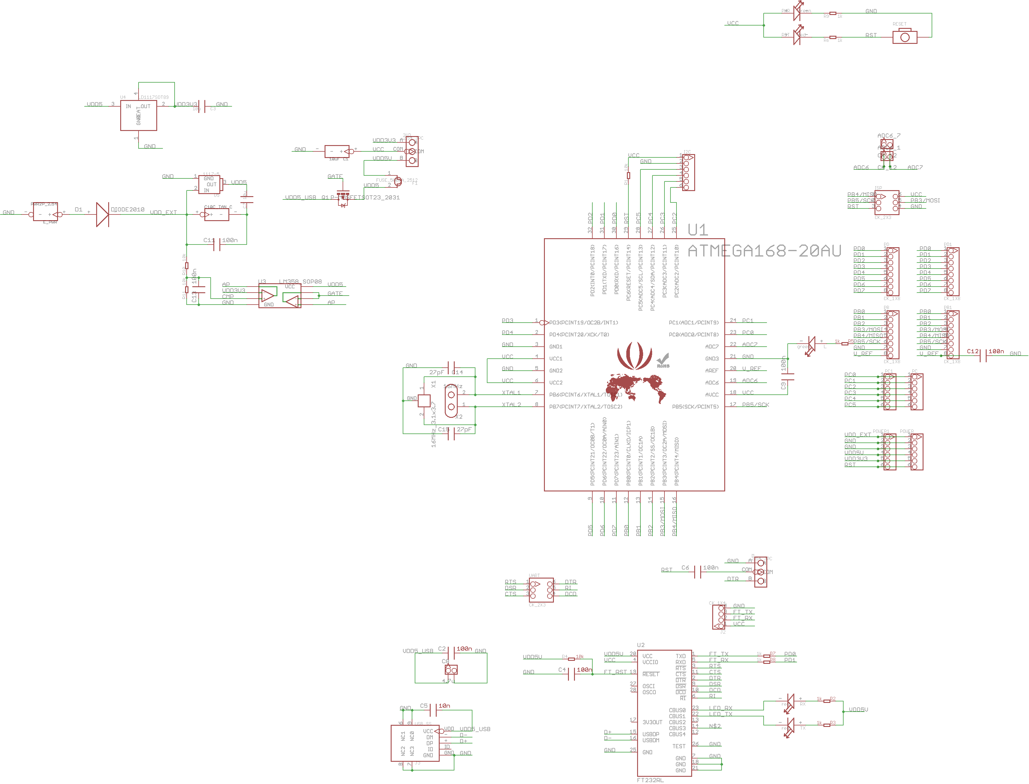
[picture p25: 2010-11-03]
docs/misc/seeeduino_board.png

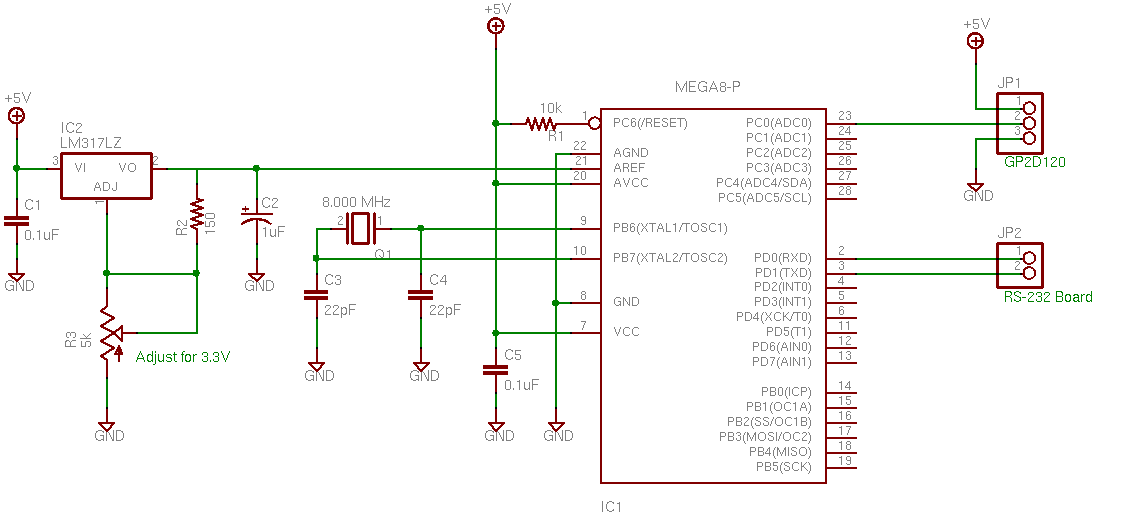
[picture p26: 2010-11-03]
docs/misc/avr_typical_circuit.png

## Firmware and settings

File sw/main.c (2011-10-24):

/* Copyright (C) 2010-2011 Magnus Olsson
 * 
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
 * You should have received a copy of the GNU General Public License
 * along with Windnode.  If not, see <http://www.gnu.org/licenses/>.
 */

#include <avr/io.h>
#include <stdio.h>
#include <stdbool.h>
#include <util/delay.h>
#include <avr/interrupt.h>
#include <string.h>
#include <stdlib.h>

#include "command.h"
#include "errno.h"
#include "swuart.h"
#include "telit.h"
#include "at.h"
#include "time.h"
#include "stackmon.h"
#include "gsm.h"

static FILE f_debug;
static FILE f_gsm;

static uint8_t dbg_rx[CONFIG_DEBUG_RX_BUF];
static uint8_t dbg_tx[CONFIG_DEBUG_TX_BUF];

static int cmd_stackdepth(char *arg, char *buf, size_t buflen)
{
	char tmp[30];

	sprintf(tmp, "Depth %d Limit %d", stackmon_maxdepth(), stackmon_stacksize());

	if (buflen >= strlen(tmp)) {
		strcat(buf, tmp);
		return strlen(tmp);
	} else
		return -ENOMEM;
}

static int cmd_gsmpwr(char *arg, char *buf, size_t buflen)
{
	if (buflen < 2)
		return -ENOMEM;

	if (!memcmp(arg, "ON", 2)) {
		strcat(buf, "UP");
		telit_power_up();
	} else {
		strcat(buf, "DN");
		telit_power_down();
	}

	return 2;
}

static int cmd_gsmrst(char *arg, char *buf, size_t buflen)
{
	if (buflen < 2)
		return -ENOMEM;

	telit_reset();
	strcat(buf, "OK");
	return 2;
}

static int cmd_gsmat(char *arg, char *buf, size_t buflen)
{
	if (at_cmd(&f_gsm, arg)) {
		strcat(buf, "FAIL");
		return 4;
	}

	strcat(buf, "OK");
	return 2;
}

static int cmd_gsmresp(char *arg, char *buf, size_t buflen)
{
	return at_response(&f_gsm, buf, buflen, 2 * HZ);
}

static int cmd_delay(char *arg, char *buf, size_t buflen)
{
	uint8_t timeout = atoi(arg);
	uint32_t t0 = time_jiffies();

	while (time_jiffies() - t0 < timeout * HZ) ;

	strcat(buf, "OK");
	return 2;
}

static int cmd_gsmstat(char *arg, char *buf, size_t buflen)
{
	int status = gsm_status(&f_gsm);
	char msg[13];
	size_t len;

	if (status < 0)
		return status;

	switch (status) {
	case GSM_DISCONNECTED:
		strcpy(msg, "DISCONNECTED");
		break;
	case GSM_REGISTERED:
		strcpy(msg, "REGISTERED");
		break;
	case GSM_SEARCHING:
		strcpy(msg, "SEARCHING");
		break;
	case GSM_ROAMING:
		strcpy(msg, "ROAMING");
		break;
	case GSM_UNKNOWN:
	default:
		strcpy(msg, "UNKNOWN");
		break;

	}

	len = strlen(msg);
	if (len > buflen)
		len = buflen;

	strcpy(buf, msg);
	return len;
}

/* Sorted by priority */
static struct command *commandlist[] = {
	CREATE_COMMAND("STACK", cmd_stackdepth),
	CREATE_COMMAND("DELAY", cmd_delay),
	CREATE_COMMAND("GSMAT", cmd_gsmat),
	CREATE_COMMAND("GSMPWR", cmd_gsmpwr),
	CREATE_COMMAND("GSMRST", cmd_gsmrst),
	CREATE_COMMAND("GSMRESP", cmd_gsmresp),
	CREATE_COMMAND("GSMSTAT", cmd_gsmstat),
	COMMANDLIST_END,
};

static void cmdline_loop(void)
{
	char in[200], out[200];
	size_t inlen;
	bool in_cmd;

	while (1) {
		in_cmd = true;
		inlen = 0;
		out[0] = '\0';
		in[0] = '\0';
		printf("> ");

		while (in_cmd) {
			int c = fgetc(stdin);
			if (c != EOF) {
				if (c == '\n' || c == '\r' ||
				    inlen == sizeof(in) - 1) {
					in[inlen] = '\0';
					cmd_exec(commandlist, in, out, sizeof(out));

					printf("%s (%d bytes)\n", out, strlen(out));
					in_cmd = false;
				} else
					in[inlen++] = c;
			}
		}
	}
}

int main(void)
{
	uint8_t cause = MCUSR;
	MCUSR = 0;

	swuart_init(SWUART_BAUD(CONFIG_DEBUG_BAUDRATE, F_CPU), &f_debug,
	    dbg_rx, sizeof(dbg_rx), dbg_tx, sizeof(dbg_tx));

	stdout = &f_debug;
	stdin = &f_debug;

	telit_init(&f_gsm);
	time_init();

	sei();

	printf("WindNode initialized, reset cause 0x%x, startup stack %d bytes\n",
	    cause, stackmon_maxdepth());

	cmdline_loop();

	while (1) {
		/* SLEEP */
	}

	return 0;
}

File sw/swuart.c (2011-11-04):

/* Copyright (C) 2010-2011 Magnus Olsson
 * 
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
 * You should have received a copy of the GNU General Public License
 * along with Windnode.  If not, see <http://www.gnu.org/licenses/>.
 */
#include <stdio.h>
#include <stdbool.h>
#include <avr/io.h>
#include <avr/interrupt.h>
#include "ringbuf.h"

#define STARTBIT (0)
#define STOPBIT (1)
#define DATAWIDTH (8)
#define TX_PRESCALER (_BV(CS22))	/* 64 */
#define RX_PRESCALER (_BV(CS01) | _BV(CS00))	/* 64 */

enum {
	UART_IDLE,
	UART_STARTBIT,
	UART_DATA,
	UART_STOPBIT,
};

struct swuart_private {
	uint8_t tx_sample;
	uint8_t tx_bitsleft;
	struct ringbuf tx_buf;
	uint8_t tx_state;
	uint8_t rx_sample;
	uint8_t rx_bitsleft;
	struct ringbuf rx_buf;
	uint8_t rx_state;
	uint8_t btime;
};

static struct swuart_private port;

static uint8_t rx_pin(void)
{
	return (CONFIG_SWUART_RX_PIN & _BV(CONFIG_SWUART_RX_BIT)) != 0;
}

static void rx_pinchange_irq(uint8_t en)
{
	if (en)
		CONFIG_SWUART_RX_PCMSK |= _BV(CONFIG_SWUART_RX_PCBIT);
	else {
		CONFIG_SWUART_RX_PCMSK &= ~(_BV(CONFIG_SWUART_RX_PCBIT));
		PCIFR |= _BV(CONFIG_SWUART_RX_PCBIT);
	}
}

static void rx_timer_irq(uint8_t en)
{
	if (en)
		TIMSK0 |= _BV(OCIE0A);
	else
		TIMSK0 &= ~(_BV(OCIE0A));
}

static void rx_timer_toggle(uint8_t on)
{
	if (on)
		TCCR0B |= RX_PRESCALER;
	else {
		TCCR0B &= ~RX_PRESCALER;
		TIFR0 |= _BV(OCF0A);
	}
}

static void tx_pin(uint8_t hi)
{
	if (hi)
		CONFIG_SWUART_TX_PORT |= _BV(CONFIG_SWUART_TX_BIT);
	else
		CONFIG_SWUART_TX_PORT &= ~(_BV(CONFIG_SWUART_TX_BIT));
}

static void tx_timer_irq(uint8_t en)
{
	if (en)
		TIMSK2 |= _BV(OCIE2A);
	else
		TIMSK2 &= ~(_BV(OCIE2A));
}

static void tx_timer_toggle(uint8_t on)
{
	if (on)
		TCCR2B |= TX_PRESCALER;
	else {
		TCCR2B &= ~TX_PRESCALER;
		TIFR2 |= _BV(OCF2A);
	}
}

ISR(CONFIG_SWUART_RX_PCVECT)
{
	uint8_t rxbit = rx_pin();

	/* Glitch-protection: Check for start bit on RX PIN */
	if (rxbit == STARTBIT) {
		/* Setup to sample startbit in btime/2 */
		TCNT0 = port.btime / 2;
		rx_timer_toggle(true);

		port.rx_state = UART_STARTBIT;
		rx_pinchange_irq(false);
	}
}

ISR(TIMER0_COMPA_vect)
{
	uint8_t rxbit = rx_pin();

	switch (port.rx_state) {
	case UART_IDLE:
		/* We should never end up here */
		break;

	case UART_STARTBIT:
		/* Check for valid startbit */
		if (rxbit == STARTBIT) {
			port.rx_bitsleft = DATAWIDTH;
			port.rx_state = UART_DATA;
		} else {
			/* Glitch-protection: return to idle if startbit has vanished */
			port.rx_state = UART_IDLE;
			rx_timer_toggle(false);
			rx_pinchange_irq(true);
		}
		break;

	case UART_DATA:
		port.rx_sample = port.rx_sample >> 1;
		port.rx_bitsleft--;

		if (rxbit)
			port.rx_sample |= _BV(DATAWIDTH - 1);

		if (port.rx_bitsleft == 0)
			port.rx_state = UART_STOPBIT;
		break;

	case UART_STOPBIT:
		/* Check for valid stopbit */
		if (rxbit == STOPBIT) {
			if (!rb_is_full(&port.rx_buf))
				rb_insert_tail(&port.rx_buf, port.rx_sample);
		}

		/* Disable timer and re-enable startbit detector */
		port.rx_state = UART_IDLE;
		rx_timer_toggle(false);
		rx_pinchange_irq(true);
		break;
	}
}

ISR(TIMER2_COMPA_vect)
{
	switch (port.tx_state) {
	case UART_IDLE:
		/* We should never end up here */
		break;

	case UART_STARTBIT:
		tx_pin(STARTBIT);
		port.tx_state = UART_DATA;
		break;

	case UART_DATA:
		tx_pin(port.tx_sample & 0x1);

		port.tx_sample = port.tx_sample >> 1;
		port.tx_bitsleft--;

		if (port.tx_bitsleft == 0)
			port.tx_state = UART_STOPBIT;
		break;

	case UART_STOPBIT:
		tx_pin(STOPBIT);

		/* Schedule work for next cycle, if available */
		if (!rb_is_empty(&port.tx_buf)) {
			port.tx_bitsleft = DATAWIDTH;
			port.tx_sample = rb_remove_head(&port.tx_buf);
			port.tx_state = UART_STARTBIT;
		} else {
			tx_timer_toggle(false);
			port.tx_state = UART_IDLE;
		}
		break;
	}
}

static int swuart_getc(FILE * stream)
{
	int ret = 0;

	rx_timer_irq(false);
	if (rb_is_empty(&port.rx_buf))
		ret = _FDEV_EOF;
	else
		ret = rb_remove_head(&port.rx_buf);
	rx_timer_irq(true);

	return ret;
}

static int swuart_putc(char c, FILE * stream)
{
	uint8_t queued = 0;

	do {
		if (port.tx_state == UART_IDLE) {
			port.tx_bitsleft = DATAWIDTH;
			port.tx_sample = c;
			port.tx_state = UART_STARTBIT;
			TCNT2 = 0;
			tx_timer_toggle(true);
			queued = 1;
		} else {
			tx_timer_irq(false);
			if (!rb_is_full(&port.tx_buf)) {
				rb_insert_tail(&port.tx_buf, c);
				queued = 1;
			}
			tx_timer_irq(true);
		}
	} while (!queued);

	return 0;
}

void swuart_init(unsigned int btime, FILE * stream, uint8_t * rx_buf,
    uint8_t rx_size, uint8_t * tx_buf, uint8_t tx_size)
{
	rb_init(&port.rx_buf, rx_buf, rx_size);
	rb_init(&port.tx_buf, tx_buf, tx_size);

	port.tx_state = UART_IDLE;
	port.rx_state = UART_IDLE;
	port.btime = btime;

	CONFIG_SWUART_RX_DIR &= ~(_BV(CONFIG_SWUART_RX_BIT));
	CONFIG_SWUART_RX_PORT |= _BV(CONFIG_SWUART_RX_BIT);	/* Pull-up */
	CONFIG_SWUART_TX_DIR |= _BV(CONFIG_SWUART_TX_BIT);
	tx_pin(STOPBIT);

	/* Baudrate */
	OCR0A = btime;
	OCR2A = btime;

	/* CTC Mode */
	TCCR0A = _BV(WGM01);
	TCCR2A = _BV(WGM21);

	fdev_setup_stream(stream, swuart_putc, swuart_getc, _FDEV_SETUP_RW);

	/* At this point, the timers are not started so its safe to unmask */
	rx_timer_irq(true);
	tx_timer_irq(true);

	/* Trigger interrupt on RX pin changes */
	PCICR |= _BV(CONFIG_SWUART_RX_PCCTRL);
	rx_pinchange_irq(true);
}

void swuart_free(void)
{
}

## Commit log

2010-10-30 Add Atmel appnote 1-wire on AVR
2010-10-30 Add WeBBS report
    WeBBS is a remote controlled (GSM) controlled weatherstation which uses GSM.
    It measures wind using ultrasonic anemometers.
2010-11-03 Make pretty modules
    First attempt to break out useful code from prototype
2010-11-03 Add some typical schematics
    These can prove useful for inspiration in later KiCad work
2010-11-16 Do not power down between between samples
    Export power management for wind sensors so it does not have to
    toggle between each sample.
2010-11-16 Add config struct and eeprom storage backend
    The config struct holds a global config for the windstation. It can
    be stored on eeprom to survive power outage and read back with basic
    integrity checking.
2010-11-24 Add software UART
2010-11-25 Interrupt-based HW UART
    Instead of using a busy-wait loop to poll the UART HW, we instead rely
    on interrupts and a ringbuffer in each direction to transmit/receive.
    This will lower the CPU load, but increases RAM usage.
2010-11-26 Mask each UART IRQ individually to improve bit-timing accuracy
    Instead of globally disabling the lock to achieve mutual exclusion to
    the ring buffers, mask each interrupt individually when needed.
    This will reduce latency for the IRQ handlers which is critical for the
    SWUART implementation.
    This also makes the ports "truly" full duplex as each port and each
    direction can work independently without being blocked when another
    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
2010-11-27 Offset SWUART RX sampling for more robust sampling
    When the startbit is detected, start sampling after half the bittime.
    This way sampling will occur in the middle of the UART data cycle and
    makes the receiver less vulnerable to inaccurate transmitters.
    We can also detect glitches on the RX pin by re-sampling the startbit
    after half the bittime, and abort sampling if it has vanished. This
    makes the receiver much more robust when running at higher baudrates
    and with a higher cpu clockcycle (where no significant delay is added
    by the interrupt handler. Baudrate 4800 is now possible!
    [swuart.c]
2010-12-08 Change programmer port to /dev/avrusb0
    This is a symbolic link created by udev to map with the correct USB
    device, to better cope with dynamic device names.
2010-12-09 Heap-based buffers for more finegrain ringbuf sizes
    Switch to heap-based memory allocation for the ringbuffer to allow for
    individual sizes for each ringbuffer instance. This will save memory
    since not all UART buffers need to be as large as the GSM buffer where
    we expect more data at a higher rate.
    This also means that each ringbuffer instance must be free'd after
    usage to prevent memory leaks.
    [config.h, swuart.c, uart.c]
2010-12-12 Add power-on LED on PB1
    This helps to debug the spontaneous restarts-problem.
    [main.c]
2010-12-21 Check for memory allocation errors during UART/SWUART init
    [swuart.c, uart.c]
2011-01-21 Add schematics for Seeduino v2.21 and GSM Playground v1.6
    These will be used as the new platform instead of SIM300-based GSM
    board from Rhydolabz.
    [GSM Playground V1_6.brd, GSM Playground V1_6.sch, Seeeduino_V2.2.brd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]
2011-02-03 Switch to Atmega328p (Seeduino-based platform)
2011-02-11 Rework SWUART to rely on pinchange IRQ to detect incoming startbits
    By using the pinchange interrupt, SWUART RX pin can be configured to
    use any of the 24 PCINT pins, instead of just the two external
    interrupt pins INT0/INT1.
    [config.h, swuart.c, wind.c]
2011-02-15 Group UART and SWUART configs
2011-03-25 Wait for device to appear before flashing (magboot)
2011-03-29 Move UART and SWUART crashcourse to docs/
    [swuart.c, uart.c]
2011-05-08 Add system timer ("jiffies")
    Adds a free-running system time counter, with configurable time periods
    (CONFIG_HZ) down to 1 millisecond. This can be used to measure relative
    time in the system.
2011-05-20 Fix timer interval calculation
    Use correct prescaler value in timer calculation (instead of
    the corresponding AVR register value..).
2011-05-22 Increase F_CPU to 16 MHz
    Arduino boards use 16 MHz external crystal.
2011-05-22 Add shared timer system
    Share a single system timer for multiple handlers and intervals using
    a sorted queue.
    timer_add() adds a timer to the queue
    timer_mod() modifies an already queued timer
    timer_del() removes a timer from the queue
    To tick the timer system, one should periodically call timer_expire().
    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
2011-05-30 Add basic GSM framework
    Adds pin config for GSM hardware and basic commands for powering
    up/down, resetting and issuing commands to the modem.
    [config.h, main.c]
2011-05-31 Remove glitch debugprints from SWUART
    [swuart.c]
2011-05-31 Add GSM I/O debug prints
    Toggle these by defining D(x) to x.
2011-06-06 Add stack monitor
    Monitors maximum stack usage by painting memory with a known canary at
    startup. Worst-case stack usage scenario can be found by periodically
    cycling through the RAM and looking for discontinuity in the stack
    canary.
    This implementation assumes NO memory is allocated on the heap and
    will break if you attempt to allocate using malloc() or such.
2011-06-16 Move SWUART RX to PORTB PB3
    This will free up PB5, which happens to be fitted with a LED useful
    for debugging (on Arduino-boards anyway).
2011-06-16 Add simplistic debug LED framework
    Adds control for the LED on PORTB PB5 (Arduino-boards). Useful for
    debug, or whatever.
2011-06-16 Print system reset cause upon initialization
    The reset cause tells if we came from a cold boot ("power-on"),
    or a brown-out. Unfortunately, we cannot detect WDT resets because
    Magboot sits inbetween and filters these events as it itself uses
    WDT to function.
    [main.c]
2011-06-16 Fix baudrate calculation for HW UART
    Consistently one off causing an offset in baudrate. This is not
    noticed at lower rates as most modern serial controllers allow
    up to -+ 10% rate, but becomes a problem at higher rates such as
    115.2 kbaud.
    This patch corrects the calculation to use an optimal baudrate div.
2011-09-16 Pass UART buffers as parameters to uart_init()
    Instead of owning its own buffer, let HWUART user pass buffers and sizes
    to init() for greater flexibility.
2011-09-16 Ensure command separator is inserted at correct position
    Basically use strcpy() rather than strcat(). This way we don't need
    to rely on command handlers to correctly terminate strings and such.
2011-10-08 Don't track GNU indent backup-files
2011-10-31 Add maxstack target
    Adds a Makefile target to estimate upper bound of stack usage. It
    sums all function frame sizes, and assume no function recursion
    occurs.

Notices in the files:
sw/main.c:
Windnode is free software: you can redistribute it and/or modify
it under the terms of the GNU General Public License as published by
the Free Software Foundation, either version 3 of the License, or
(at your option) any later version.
